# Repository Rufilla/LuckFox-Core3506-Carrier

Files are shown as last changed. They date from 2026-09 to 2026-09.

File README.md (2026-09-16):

<!-- {{LOGO — add the Rufilla logo here once an asset lives in this repo, e.g. ![Rufilla](docs/images/rufilla-logo.png)}} -->

# Foxbridge — Luckfox Core3506 carrier board


<!-- Add build and release badges when CI is set up. -->

A carrier board for the [Luckfox Core3506](https://wiki.luckfox.com/Core3506/Introduction/)
system-on-module (SoM), for anyone who wants the RK3506 on a Raspberry Pi Model B-sized board
(85 × 56 mm) with Ethernet, USB-C, a DSI display & a 40-pin header. Designed in KiCad 10 by
Rufilla Ltd., from the [Luckfox Lyra Pi](https://www.luckfox.com/Luckfox-Lyra-Pi) reference
design. Revision A is a prototype: it has been built & brought up, with three hardware faults.

| | |
|---|---|
| **Client** | Internal |
| **Project code** | Foxbridge |
| **Status** | Prototype — Revision A built & reworked; Revision B in design |

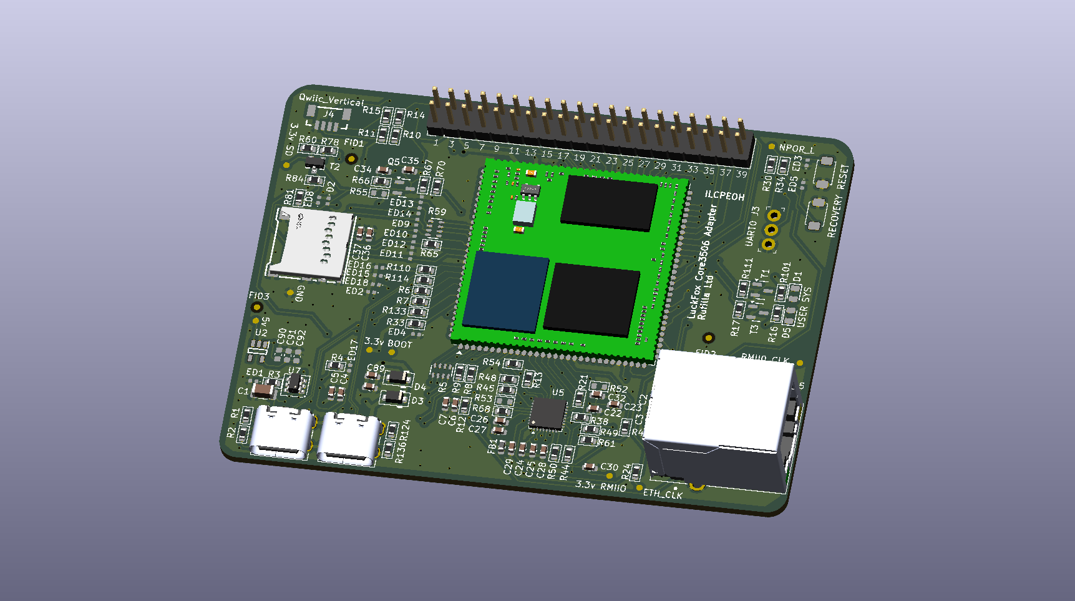
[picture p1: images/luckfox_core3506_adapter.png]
Foxbridge carrier board


> **Revision A has been built & brought up with three hardware faults.** USB host (OTG1) does
> not work without two reworks. Read the [errata](docs/errata.md) before ordering boards.

## Overview

The board breaks the Core3506 SoM out to a Raspberry Pi Model B footprint. Each subsystem has
its own schematic sheet; [docs/design-notes.md](docs/design-notes.md) explains how each one
works & why.

- **USB-C ×2** — OTG0 (device, flashing & 5 V power input) & OTG1 (host, 500 mA current limit)
- **10/100 Ethernet** — CH182H2 PHY on RMII0, HR911105A RJ45 with integrated magnetics
- **MIPI DSI** — 2-lane, 22-pin 0.5 mm FPC for the Luckfox 7" DSI touchscreen (SKU 25265)
- **40-pin header** — Raspberry Pi-compatible pinout
- **microSD** — TF-110 socket with power switching; see errata E4 for the eMMC SoM
- **RESET & RECOVERY buttons**; UART0 header & Qwiic connector (both not fitted)
- **4-layer, 1.6 mm, impedance-controlled** — built for JLCPCB Economic PCBA

Out of scope for this design:

- No on-board 3.3 V regulator is fitted; the SoM supplies `VCC_3V3`. U2 is reserved for a
  future Wi-Fi/Bluetooth module.
- No Wi-Fi or Bluetooth.
- Power comes only from 5 V on the OTG0 USB-C port — no barrel jack & no PoE.
- The microSD slot does not work with the Core3506 variant that has on-module eMMC.
- No MASKROM button & no mounting holes in Revision A.

## Requirements

**Hardware**

- Luckfox Core3506 SoM (RK3506), fitted to a Foxbridge carrier board, revision A
- USB-C cable on OTG0 for power & flashing; 3.3 V USB-UART on the UART0 header for a console
- Optional: Luckfox 7" DSI touchscreen (SKU 25265), microSD card, Ethernet cable

**Software**

- KiCad 10.0 or later. Checked with 10.0.6.
- [Fabrication Toolkit](https://github.com/bennymeg/JLC-Plugin-for-KiCad) plugin, to regenerate
  the JLCPCB production files
- Third-party symbol & footprint libraries, needed only to update a part from its library:

| Nickname in the design | Library | Install from |
|---|---|---|
| `PCM_SparkFun-*` | SparkFun KiCad Libraries | Plugin & Content Manager (PCM) |
| `PCM_*_AKL` | [Alternate KiCad Library](https://github.com/DawidCislo/Alternate-KiCad-Library) | PCM |
| `PCM_JLCPCB*` | [JLCPCB KiCad Library](https://github.com/CDFER/JLCPCB-Kicad-Library) | PCM, after adding CD_FER's repository |
| `digikey-footprints`, `dk_*` | [Digi-Key KiCad Library](https://github.com/Digi-Key/digikey-kicad-library) | Clone & register by hand (J3 only) |

PCM libraries resolve only with the default nickname prefix `PCM_` (**Preferences → Packages
& Updates**).

## Getting the source

```bash
git clone https://github.com/Rufilla/LuckFox-Core3506-Carrier.git
cd LuckFox-Core3506-Carrier
```

## Building

Open `luckfox_core3506_adapter.kicad_pro` in KiCad. The schematic & board carry a copy of every
symbol & footprint, so the design opens, plots & runs ERC/DRC without the third-party libraries
above. Parts specific to this board are in the project library `lib/` (nickname `Foxbridge`),
with their 3D models embedded.

Regenerate the fabrication outputs from the PCB editor with **Tools → External Plugins →
Fabrication Toolkit**. It reads `fabrication-toolkit-options.json`, excludes do-not-populate
parts & writes the Gerbers, drill, BOM & placement files that are committed in `production/`.

## Flashing / deployment

Ordering Revision A from JLCPCB, in full, is in
[docs/manufacturing.md](docs/manufacturing.md#order-from-jlcpcb). In short:

| File | Upload as |
|---|---|
| `production/luckfox_core3506_adapter.zip` | Gerbers & drill |
| `production/bom.csv` | Bill of materials |
| `production/positions.csv` | Component placement (CPL) |

Order Economic PCBA. Three parts are soldered by hand — J1 (RJ45), H1 (2 × 20 pin header) &
U1 (Core3506) — and the placement preview needs the rotation & offset corrections listed in the
manufacturing notes.

> **NOTE:** the files in `production/` reproduce Revision A exactly, including the faults in
> [docs/errata.md](docs/errata.md). Boards built from them need the E1 & E2 reworks before USB
> host works.

## Usage

Power the board from 5 V over the OTG0 USB-C port; the same port flashes the SoM. The console
is on the UART0 header. Ethernet, DSI & the 40-pin header need no board-level configuration.

Before trusting a freshly built board, check it against the reworks in
[docs/errata.md](docs/errata.md): R3 moved (E1) & R6/R7 bridged (E2). Photographs of both are
in `images/`.

## Testing

Run electrical rules & design rules from the project directory:

```bash
kicad-cli sch erc luckfox_core3506_adapter.kicad_sch
kicad-cli pcb drc --schematic-parity luckfox_core3506_adapter.kicad_pcb
```

Every outstanding ERC & DRC report is listed, with its cause & whether it is a real fault, in
[docs/manufacturing.md](docs/manufacturing.md#erc--drc-status). Schematic parity & unconnected
items are both zero.

## Project structure

```
luckfox_core3506_adapter.kicad_pro   KiCad project; the root schematic, 10 sheets & board sit beside it
lib/                                 Project symbol library & footprint library
production/                          Revision A files as ordered from JLCPCB: Gerbers & drill (.zip), BOM, placement, IPC netlist
docs/                                Design notes, errata, manufacturing notes & the Revision B checklist
images/                              Board render & rework photographs
```

Documentation:

- [Design notes](docs/design-notes.md) — how each subsystem works & why
- [Errata](docs/errata.md) — Revision A faults, reworks & limitations
- [Manufacturing](docs/manufacturing.md) — stack-up, ordering from JLCPCB, ERC/DRC status
- [Revision B checklist](docs/rev-b-checklist.md) — changes planned for the respin

## Security

Report a security problem to [hello@rufilla.com](mailto:hello@rufilla.com) rather than through
a public issue. This repository holds hardware design files only, so no software bill of
materials (SBOM) is produced; the bill of materials for the board is `production/bom.csv`.

## Contributing

Report problems & suggestions through GitHub issues, & send changes as pull requests.

## Licence

Copyright 2026 Rufilla Ltd. Licensed under the [Apache License 2.0](LICENSE).

Symbols, footprints & 3D models copied from third-party libraries remain under their own
licences.

## Support

Rufilla Ltd · Building D5, Culham Campus, Abingdon, Oxfordshire, UK, OX14 3DB
[hello@rufilla.com](mailto:hello@rufilla.com) · +44 (0)1865 601201 · [www.rufilla.com](https://www.rufilla.com)

© 2026 Rufilla Ltd

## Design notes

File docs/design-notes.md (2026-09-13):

# Design notes

How each subsystem of Revision A works & why it was designed that way. Faults found at
bring-up are in [errata.md](errata.md); fabrication detail is in
[manufacturing.md](manufacturing.md).

Contents: [Schematic](#schematic) · [Power](#power) · [USB](#usb) · [Ethernet](#ethernet) ·
[microSD](#microsd) · [DSI display](#dsi-display) · [Boot & reset](#boot--reset) ·
[Debug](#debug) · [LEDs](#leds) · [SoM pin mapping](#som-pin-mapping)

---

## Schematic

Hierarchical, 10 sheets. The SoM, U1 (`Core3506_multipart`), is an 8-unit symbol whose units
are placed on the sheets that use them.

| Page | Sheet |
|---|---|
| 1 | Contents & revisions |
| 2 | Block diagram |
| 3 | Power tree |
| 4 | Power regulation |
| 5 | USB interfaces |
| 6 | Ethernet |
| 7 | TF card |
| 8 | DSI |
| 9 | GPIO header & boot keys |
| 10 | Misc — test points, LEDs, fiducials |

## Power

- **Input:** 5 V from the OTG0 USB-C port (H5) through D3 (MBR230SFT Schottky) to
  `VCC5V0_SYS`. D3 stops OTG1 VBUS back-feeding OTG0.
- **`VCC5V0_SYS` TVS:** ED17 (ESD5451N, 5 V stand-off, 13 V clamp).
- **3.3 V:** supplied by the PMIC on the SoM. U2 (ME6217C33M5G LDO) is not fitted; it is
  reserved for a future Wi-Fi/Bluetooth module.
- **OTG1 VBUS:** U7 (TPS2553DBVR) power switch, current limit set to 500 mA by R4 (56 kΩ).
  ED1 (ESD5451N) protects its output. Does not switch on in Revision A — see errata E1.
- **Ethernet analogue supply:** FB1 (330 Ω at 100 MHz) isolates `VCCA3V3_RMII0` from `VCC_3V3`.

## USB

### OTG0 — device, flashing & power input (H5)

- CC pull-downs (Rd, i.e. USB-C sink): R136 & R124, 5.1 kΩ.
- D+/D− series resistors R110 & R114, 22 Ω — the same value that breaks OTG1 (errata E2).
- ESD: ED18 & ED2 (ESD5341N).
- VBUSDET (U1 pin 113) tied to `VCC_3V3` through R133 (10 kΩ); ID (pin 112) left
  unconnected. Both follow the Lyra Pi.

### OTG1 — host, 500 mA (H6)

- CC pull-ups (Rp, i.e. USB-C source): R1 & R2, 56 kΩ to OTG1 VBUS, advertising Default USB
  power.
- D+/D− series resistors R6 & R7, 22 Ω. **Wrong for high speed** — see errata E2.
- ESD: ED15 & ED16 (ESD5341N).

## Ethernet

### CH182H2 PHY (U5)

> **NOTE:** the CH182H2 is not strap-compatible with the CH182H1. The RMII-mode strap moved
> from pin 27 (COL) on the H1 to pin 8 (RXDV) on the H2. Use the H2 tables in datasheet
> CH182DS1; CH182H1 designs give the wrong strap assignments.

| Function | Setting | Parts |
|---|---|---|
| PHY address | 0x01 (PA0 = 1 via LED0 pull-up, PA1 = 0 via LED1 pull-down) | — |
| Mode | RMII: RXDV (pin 8) pulled high | R50, 4.7 kΩ |
| Clock | MAC drives 50 MHz REFCLK; CLKCTL pulled high | R38, 4.7 kΩ |
| 25 MHz XI | From SoM `ETH_CLK0_25M_OUT`; no crystal | R24, 0 Ω |
| LOS | Low — LED function, not wake-on-LAN | R61, 4.7 kΩ to GND |
| RSTB | Internal pull-up is enough | R52, 4.7 kΩ, not fitted |
| Idle state | CRS_DV & RXER pulled low | R45 & R68, 4.7 kΩ |

### RJ45 (J1, HR911105A)

- Integrated magnetics give galvanic isolation, so the MDI pairs carry no ESD diodes.
- Centre-tap decoupling: C2 & C3, 100 nF.
- Link & activity LEDs driven from the CH182H2 LED0 & LED1 pins.

### Routing

- MDI: 100 Ω differential; intra-pair match within 1.3 mm; ≥ 0.75 mm between pairs.
- RMII: 50 Ω single-ended; data matched to REF_CLK within 10 mm.

## microSD

- Socket: J2 (TF-110, LCSC C266613).
- Power: Q5 (SI2301CDS P-channel MOSFET) switches `VCC_3V3` to `VCC3V3_SD`, gate driven from
  `SDMMC_PWREN` through R70.
- Card detect: T2 (MMBT3906 PNP).
- ESD: ED8–ED14 (ESD5341N) on CLK, CMD, D0–D3 & card detect; D2 on `VCC3V3_SD`.
- Series resistors: R59 (4 × 22 Ω array) on D0–D3, R65 (22 Ω) on CMD. CLK has none.
- Routing: matched to CLK within about 7.5 mm, inside the tolerance for 50 MHz. CMD, D2 & D3
  change to B.Cu through two vias each.

The slot is electrically dead when the SoM has on-module eMMC — a limitation of the RK3506,
explained in errata E4.

## DSI display

Target display: Luckfox 7" DSI touchscreen (SKU 25265) — 800 × 480 IPS, 5-point capacitive
touch — through H4 (22-pin 0.5 mm FPC, LCSC C262668). Sold by
[Luckfox](https://www.luckfox.com/EN-7inch-DSI-Touchscreen) & Waveshare.

| FPC pin | Signal | Connection |
|---|---|---|
| 1 | `VCC_3V3` | Display power |
| 2 | `I2C2_SDA` | Touch; R15 22 Ω series, R11 3.3 kΩ pull-up |
| 3 | `I2C2_SCL` | Touch; R14 22 Ω series, R10 3.3 kΩ pull-up |
| 4, 7, 10, 13, 16, 19, 22 | GND | |
| 5 | `LCD_IO1` | GPIO1_C4 (U1 pin 34) — LCD reset, R12 10 kΩ pull-up |
| 6 | `LCD_IO0` | GPIO0_B7 (U1 pin 63) — backlight enable |
| 8, 9, 11, 12 | — | Not connected |
| 14–15 | `DSI_TX_CLKN/P` | U1 pins 1 & 2; 2.2 Ω series (R5 array) |
| 17–18 | `DSI_TX_D1N/P` | U1 pins 4 & 5; 2.2 Ω series (R5 array) |
| 20–21 | `DSI_TX_D0N/P` | U1 pins 7 & 8; 2.2 Ω series (R8, R9) |

Departures from the Lyra Pi:

- **No LCD power switch** (WPM3407-3/TR). The board is always powered from USB, & the DSI
  driver sequences reset independently of power.
- **No backlight driver** (TCS7191A). The display has its own; only an enable is needed.
- **2.2 Ω instead of 0 Ω** on all six DSI lines, for consistent damping.
- **No ESD on the FPC.** The connector is internal, & the DSI lanes are sensitive to added
  capacitance.

`I2C2_SDA` (U1 pin 43, GPIO1_B3) & `I2C2_SCL` (U1 pin 36, GPIO1_C2) are shared by the touch
panel, the 40-pin header (H1 pins 3 & 5) & the Qwiic connector, with no jumpers.

## Boot & reset

- **RESET** (Key1): pulls `NPOR_L` (U1 pin 80) low through R30 (100 Ω), ESD by ED3. The SoM
  PMIC drives `NPOR_L` push-pull, so there is no external pull-up — as on the Lyra Pi.
- **RECOVERY** (Key2): pulls `SARADC_IN1` low through R34 (100 Ω), ESD by ED5. A key read by
  software after boot; it does **not** enter maskrom (errata E5).
- **Maskrom strap:** `SARADC_IN0_BOOT` (U1 pin 114) reaches test point TP6 through R33
  (100 Ω), ESD by ED4. No button is fitted.

## Debug

Neither connector is fitted in Revision A.

- **J3** — UART0, 3-pin 2.54 mm header: U1 pins 56 & 57 (GPIO0_C7, GPIO0_C6) & GND. UART0 is
  also on the 40-pin header.
- **J4** — Qwiic/STEMMA QT (JST-SH 4-pin): `I2C2_SDA`, `I2C2_SCL`, `VCC_3V3`, GND.

## LEDs

Both green 0805, each switched low-side by an SS8050 NPN from a SoM GPIO.

| LED | Transistor | GPIO | Base resistor | LED resistor |
|---|---|---|---|---|
| D1 (SYS) | T1 | GPIO1_A0 (U1 pin 55) | R111, 1 kΩ | R101, 470 Ω |
| D5 (USER) | T3 | GPIO1_A6 (U1 pin 49) | R17, 1 kΩ | R16, 470 Ω |

## SoM pin mapping

| U1 unit | Sheet | Signals |
|---|---|---|
| 1 | Power regulation | `VCC5V0_SYS`, `VCC_3V3`, `VCC_1V8` |
| 2 | USB interfaces | OTG0 D+/D− (108–109), OTG1 D+/D− (110–111), ID (112), VBUSDET (113) |
| 3 | Ethernet | RMII0, `ETH_CLK0_25M_OUT`, MDC/MDIO |
| 4 | TF card | SDMMC (101–106) |
| 5 & 6 | GPIO header & boot keys | `NPOR_L` (80), SARADC, GPIO0_B1–B6, GPIO0_C6–C7, GPIO1_A3–A5, GPIO1_D2–D3 |
| 7 | DSI | DSI CLK, D0 & D1 (1–8), `LCD_IO0` (63), `LCD_IO1` (34) |
| 8 | Misc | LED drive & power |

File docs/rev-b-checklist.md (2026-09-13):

# Revision B checklist

Changes planned for the respin. Causes & reworks for the faults are in [errata.md](errata.md).

## Faults — must fix

- [ ] **E1 — OTG1 VBUS switch.** Connect R3 pin 1 to U7 pin 1 (IN), not pin 6 (OUT).
- [ ] **E2 — USB series resistors.** R6 & R7 → 0 Ω or removed; the same for R110 & R114 on OTG0.
- [ ] **E3 — USB-C spacing.** Move H5 & H6 apart so two cables fit at once.

## Improvements

- [ ] **MASKROM button** from `SARADC_IN0_BOOT` to GND through R33 & ED4, labelled MASKROM.
      It is the only input that makes the RK3506 BootROM enter maskrom (errata E5).
- [ ] **Key2** — relabel from RECOVERY to USER or KEY, or remove it if no firmware reads
      `SARADC_IN1`.
- [ ] **U7 EN to a free GPIO**, instead of a fixed pull-up. Linux can then power-cycle OTG1, &
      `vcc5v0_otg1` gets a `gpio` property instead of `regulator-fixed` with `always-on`.
- [ ] **U7 FAULT# to a free interrupt-capable GPIO** (open-drain). Linux can then log OTG1
      over-current & thermal shutdown instead of browning out silently.
- [ ] **Silkscreen warning beside J2:** "SD slot non-functional with on-module eMMC SoM
      (Core3506-0808)" (errata E4).
- [ ] **Silkscreen:** align the 40-pin header numbering on the bottom side, & raise its text
      thickness to 0.15 mm.
- [ ] **Mounting holes:** add four, one in each corner.
- [ ] **Header pins** for `SARADC_IN0_BOOT` & `NPOR_L`, which are test points only today.

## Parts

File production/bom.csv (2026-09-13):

Designator | Footprint | Quantity | Value | LCSC Part #
C1 | 1206 | 1 | 100uF | C15008
C2, C23, C24, C26, C28, C29, C3, C32, C34, C35, C37, C4, C5, C6, C88 | 0603 | 15 | 100nF | C14663
C22, C30, C36 | 0603 | 3 | 4.7uF | C19666
C25, C27 | 0603 | 2 | 1uF | C15849
C7, C89 | 0603 | 2 | 10uF | C19702
D1 | D_0805 | 1 | SYS | C2297
D2, ED10, ED11, ED12, ED13, ED14, ED15, ED16, ED18, ED2, ED3, ED4, ED5, ED8, ED9 | 0402 | 15 | ESD5341N | C20612964
D3 | D_SOD-123F | 1 | MBR230SFT | C5377812
D4 | D_SOD-123F | 1 | SMF5.0A | C19077498
D5 | D_0805 | 1 | USER | C2297
ED1, ED17 | 0402 | 2 | ESD5451N | C2936977
FB1 | 0603 | 1 | 330Ω@100MHz | C88989
H4 | FPC_1x22_P0.5mm_Horizontal_BottomContact | 1 | Conn_01x22_FPC_0.5mm | C262668
H5, H6 | TYPE-C_16PIN_2MD_073 | 2 | TYPE-C_16PIN_2MD__073_ | C2765186
J1 | HANRUN_HR911105A | 1 | HR911105A | C12074
J2 | TF-SMD_TF-110 | 1 | TF-110 | C266613
KEY1 | SW_TS-1088-AR02016 | 1 | RESET | C720477
KEY2 | SW_TS-1088-AR02016 | 1 | RECOVERY | C720477
Q5 | Q_SOT-23 | 1 | SI2301CDS-T1-GE3 | C10487
R1, R2, R4 | 0603 | 3 | 56k | C23206
R10, R11 | 0603 | 2 | 3.3k | C22978
R101, R16 | 0603 | 2 | 470R | C23179
R110, R114, R14, R15, R42, R44, R48, R6, R65, R7 | 0603 | 10 | 22R | C23345
R111, R17, R78, R81 | 0603 | 4 | 1k | C21190
R12, R133, R60, R67, R70, R84 | 0603 | 6 | 10k | C25804
R124, R136 | 0603 | 2 | 5.1k | C23186
R13, R21, R24 | 0603 | 3 | 0R | C21189
R25, R26 | 0603 | 2 | 510R | C23193
R3, R66 | 0603 | 2 | 100k | C25803
R30, R33, R34 | 0603 | 3 | 100R | C22775
R38, R45, R49, R50, R61, R68 | 0603 | 6 | 4.7K | C23162
R5 | R_0603x4 | 1 | 2.2Ω | C12002
R54 | 0603 | 1 | 1.8k | C4177
R59 | R_0603x4 | 1 | 22R | C12008
R8, R9 | 0603 | 2 | 2.2Ω | C22939
T1, T3 | Q_SOT-23 | 2 | SS8050 200-350 | C2150
T2 | SOT23-3 | 1 | MMBT3906 | C2149
U5 | QFN-32-1EP_5x5mm_P0.5mm_EP3.45x3.45mm | 1 | CH182H2 | C41427683
U7 | SOT-23-6 | 1 | TPS2553DBVR | C55266

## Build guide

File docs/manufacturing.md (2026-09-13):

# Manufacturing

Stack-up, impedance control, ordering Revision A from JLCPCB & the current ERC/DRC results.

---

## Stack-up

JLCPCB **JLC04161H-3313**: 4 layers, 1.6 mm, ENIG. Values below are JLCPCB's; the KiCad board
stack-up rounds them.

| Layer | Thickness | Use |
|---|---|---|
| F.Cu | 35 µm (1 oz) | Signals & components |
| Prepreg 3313 | 0.0994 mm, εr 4.05 | |
| In1.Cu | 15.2 µm (0.5 oz) | GND plane |
| Core | 1.265 mm, εr 4.6 | |
| In2.Cu | 15.2 µm (0.5 oz) | 3.3 V & 5 V planes |
| Prepreg 3313 | 0.0994 mm, εr 4.05 | |
| B.Cu | 35 µm (1 oz) | Signals |

## Impedance control

Net classes are calculated for microstrip on F.Cu over the In1.Cu GND plane.

| Net class | Track width | Pair gap | Target |
|---|---|---|---|
| DSI | 0.09 mm | 0.13 mm | 100 Ω differential |
| Ethernet (MDI) | 0.09 mm | 0.13 mm | 100 Ω differential |
| USB | 0.117 mm | 0.13 mm | 90 Ω differential |
| RMII | 0.13 mm | — | 50 Ω single-ended |
| Power | 0.6 mm | — | — |
| Default | 0.2 mm | — | — |

Stitching vias surround the high-speed signals on F.Cu only. B.Cu carries just short layer
transitions of those signals, & its reference plane is In2.Cu.

JLCPCB's fabrication limits are encoded as custom DRC rules in
`luckfox_core3506_adapter.kicad_dru`. Track width & spacing minima are in **Board Setup →
Design Rules → Constraints** instead.

## Order from JLCPCB

> **NOTE:** the files in `production/` reproduce Revision A exactly, including the faults in
> [errata.md](errata.md). Boards built from them need the E1 & E2 reworks before USB host
> works.

The files were generated by the Fabrication Toolkit plugin
([JLC-Plugin-for-KiCad](https://github.com/bennymeg/JLC-Plugin-for-KiCad)) using
`fabrication-toolkit-options.json`, which excludes parts marked do-not-populate (DNP).

| File | Upload as |
|---|---|
| `production/luckfox_core3506_adapter.zip` | Gerbers & drill |
| `production/bom.csv` | Bill of materials |
| `production/positions.csv` | Component placement (CPL) |

Order Economic PCBA. JLCPCB does not assemble three parts, which are soldered by hand: J1
(HR911105A RJ45), H1 (2 × 20 pin header) & U1 (Core3506). JLCPCB rejected U1 for assembly.

### Correct the placement file

The toolkit exports with `AUTO TRANSLATE` (origin correction) on. Make these changes in
JLCPCB's placement preview after uploading `positions.csv`:

1. Remove U1 from the placement list.
2. Move H5 & H6 (USB-C, LCSC C2765186) by **+1.6 mm in Y**.
3. Rotate:

| Ref | Part | Rotation |
|---|---|---|
| J1 | HR911105A (RJ45) | +180° |
| T1 | SS8050 | +180° |
| T2 | MMBT3906 | +180° |
| T3 | SS8050 | +180° |
| Q5 | SI2301CDS | +180° |
| U5 | CH182H2 (Ethernet PHY) | −90° |
| R5 | 2.2 Ω array (4 × 0603) | +90° |
| R59 | 22 Ω array (4 × 0603) | +90° |

## ERC & DRC status

Observed with KiCad 10.0.6, its bundled libraries & the SparkFun library. Run from the project
directory:

```bash
kicad-cli sch erc luckfox_core3506_adapter.kicad_sch
kicad-cli pcb drc --schematic-parity luckfox_core3506_adapter.kicad_pcb
```

Where:
- `--schematic-parity` also compares the board against the schematic

Without the third-party libraries installed, both reports add one warning per part that uses
them (`lib_symbol_issues`, `footprint_link_issues`, `lib_footprint_issues`). Those warnings
concern the library tables only, not the design.

### ERC

| Report | Cause | Real fault |
|---|---|---|
| Power output connected to power output, `VCC_3V3` | The SoM PMIC drives `VCC_3V3` & a `PWR_FLAG` is also placed on it | No |
| J2 pin 4 (VDD) not driven | Supplied through Q5, which ERC does not treat as a source | No |
| `#PWR01` (GND) not driven | No `PWR_FLAG` on GND | No |
| 4 × `C_Small`, 1 × `Qwiic_Vertical` differ from library | The design copies differ from the current library versions | No |

### DRC

| Count | Report | Cause |
|---|---|---|
| 26 | Copper to board edge, U1 | Castellated SoM pads beside the cut-out; manufacturable |
| 16 | Silkscreen clipped by board edge, U1 | SoM outline overlaps the cut-out; the fab clips it |
| 8 | Hole clearance, H5 & H6 | USB-C GND pads 0.165 mm from the connector's locating holes; rule is 0.25 mm |
| 1 | Silkscreen text thickness | 40-pin header numbering is 0.1 mm, below the 0.15 mm rule |
| 6 | Footprint differs from library, ED9–ED14 | Board copies of `Diode_SMD:D_0402_1005Metric` differ from the current library |
| 0 | Schematic parity | |
| 0 | Unconnected items | |

The ESD diodes (D2, ED1–ED5, ED8–ED18) are DFN1006 parts on `D_0402_1005Metric` footprints.
The two land patterns are close — 0.59 × 0.64 mm pads at 0.97 mm pitch against 0.50 × 0.60 mm
at 0.80 mm for `D_DFN1006-2L` — & the 0402 pads cover the DFN1006 terminals. Revision A was
assembled on them.

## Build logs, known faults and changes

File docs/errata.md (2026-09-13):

# Revision A errata

Faults & limitations found while bringing up Revision A, with the rework applied to the
built boards. The Revision B changes are tracked in [rev-b-checklist.md](rev-b-checklist.md).

| ID | Problem | Severity | Rework on Revision A |
|---|---|---|---|
| [E1](#e1-otg1-vbus-switch-never-turns-on) | OTG1 VBUS switch never turns on | Critical | Yes — R3 moved |
| [E2](#e2-series-resistors-break-usb-high-speed) | 22 Ω series resistors break USB high speed | Critical | Yes — R6 & R7 bridged |
| [E3](#e3-usb-c-connectors-too-close) | USB-C connectors too close for two cables | Minor | None possible |
| [E4](#e4-microsd-slot-dead-with-the-emmc-som) | microSD slot dead with the eMMC SoM | Limitation | None possible |
| [E5](#e5-recovery-button-does-not-enter-maskrom) | RECOVERY button does not enter maskrom | Minor | Use TP6 |

---

## E1: OTG1 VBUS switch never turns on

**Symptom:** no VBUS on the OTG1 USB-C port (H6); USB devices are not powered.

**Cause:** U7 (TPS2553, active-high EN) has no pull-up to its input. As built:

```
U7 OUT (pin 6) ── R3 100 kΩ ──┬── EN (pin 3)
                              ├── FAULT# (pin 4)
                              └── C4 100 nF ── GND
```

R3 pulls EN up to OUT, which stays at 0 V until the switch is on, so EN never rises. FAULT#
is also tied directly to EN.

**Rework (applied 2026-04-12):** lift R3 pin 1 off OUT & wire it to U7 pin 1 (IN), making R3
an EN pull-up to `VCC5V0_SYS`. 5 V was confirmed at H6.

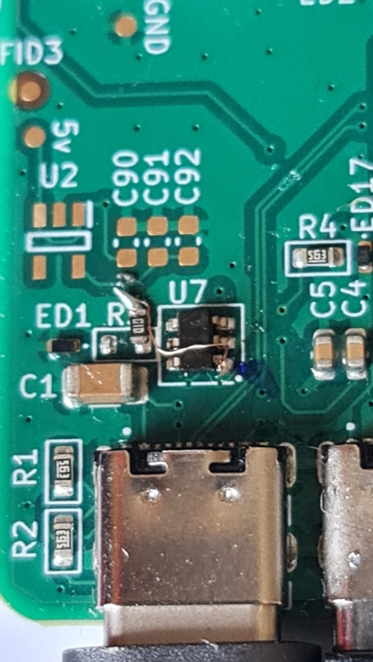
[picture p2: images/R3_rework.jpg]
E1 rework — R3 wired to U7 pin 1


**Revision B:** connect R3 pin 1 to IN, not OUT. Check the FAULT#/EN auto-retry network against
the TPS2553 datasheet (SLVS841) before layout, or drive EN & read FAULT# from GPIOs as
proposed in the checklist.

## E2: series resistors break USB high speed

**Symptom:** the OTG1 host port enumerates no device. Reproduced with a USB 3 flash drive &
a USB 2 stick, so neither the device nor the cable is at fault. Kernel log:

```
usb usb1-port1: Cannot enable. Maybe the USB cable is bad?
usb usb1-port1: attempt power cycle
```

**Cause (found 2026-04-13):** R6 & R7, 22 Ω in series with D+/D− between H6 & the SoM. In
high-speed mode the PHY provides its own 45 Ω termination; the added resistance attenuates
the chirp handshake during port reset, & it fails. 22 Ω suits full-speed signalling only.
The Lyra Pi uses 2.2 Ω, effectively a 0 Ω placeholder.

**Rework:** replace R6 & R7 with 0 Ω, or bridge each pair of pads with solder. No software
change is needed.

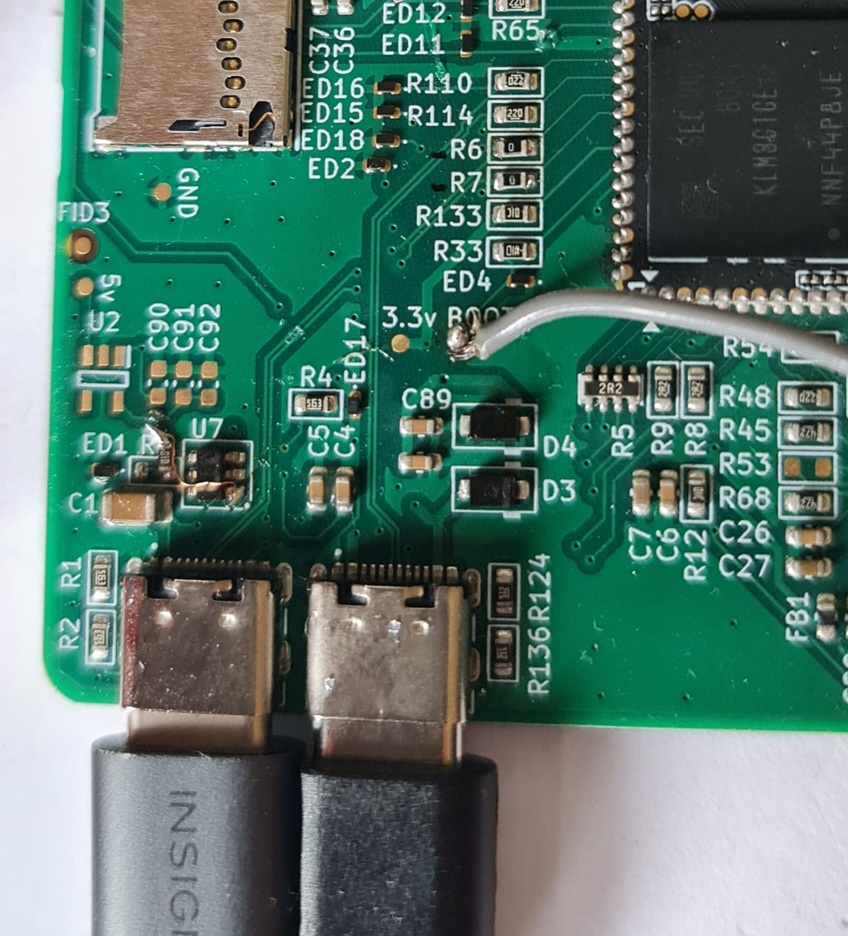
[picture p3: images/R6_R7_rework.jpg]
E2 rework — R6 & R7 bridged


**Revision B:** R6 & R7 → 0 Ω, or remove them. OTG0 has the same 22 Ω values (R110, R114)
& should get the same change; it has not been reworked.

## E3: USB-C connectors too close

**Symptom:** H5 (OTG0) & H6 (OTG1) are so close that two USB-C cables cannot be plugged in
at once — the plug overmoulds collide.

**Revision B:** increase the centre-to-centre spacing. Allow for overmoulds up to about 12 mm
wide.

## E4: microSD slot dead with the eMMC SoM

**Symptom:** the Core3506-0808 SoM does not see a card in J2.

**Cause:** the RK3506 has one SDMMC controller (`mmc@ff480000`). The Core3506-0808 connects
its 8 GB eMMC to that controller permanently, so the carrier's slot has no controller to use.
This is a limitation of the SoC — J2 is wired correctly & no rework can fix it. The RV1106, by
comparison, has two MMC controllers.

Confirmed by the Forlinx OK3506 manual, by Luckfox selling separate SD-boot & flash-boot Lyra
SKUs, & on Revision A: with the eMMC idbloader zeroed, the BootROM entered maskrom instead of
booting from SD.

**Workarounds:** a Core3506 variant without eMMC
([Luckfox](https://www.luckfox.com/Core3506?ci=672)) makes the slot work on the same board.
With the eMMC SoM, use USB mass storage on OTG1 (after the E1 & E2 reworks) or SPI flash on
the 40-pin header.

**Revision B:** keep the slot, which the eMMC-less SoM needs, & add a silkscreen warning
beside J2.

## E5: RECOVERY button does not enter maskrom

**Symptom:** holding RECOVERY (Key2) during reset does not put the RK3506 into maskrom.

**Cause:** the board copies the Lyra Pi's net names, & the Lyra Pi has two boot inputs on
different ADC pins. Foxbridge fitted the button to the wrong one. The difference only showed at
bring-up, because the Core3506 cannot be booted before it is soldered to a carrier.

| Lyra Pi key | SoC pin | Purpose | On Foxbridge |
|---|---|---|---|
| `MASKROM_Key` | `SARADC_IN0_BOOT` | Held low at power-on reset → BootROM enters maskrom | No button — R33, ED4 & test point TP6 only |
| `RECOVERY_Key` | `SARADC_IN1` | Key read by U-Boot or Linux; no effect on the BootROM | Key2, labelled RECOVERY |

**Enter maskrom on Revision A** by one of:

1. Shorting TP6 to GND during power-on reset. This is what the missing MASKROM button would
   do.
2. Shorting the MASKROM test points on the Core3506 itself during power-up.
3. Invalidating the eMMC idbloader, so the BootROM falls through to USB maskrom.

   > **NOTE:** this erases the bootloader. The board will not boot again until it is
   > reflashed over USB in maskrom mode.

   Run `rkdeveloptool ef`, or zero the first sectors of the eMMC.

**Revision B:** fit a MASKROM button from `SARADC_IN0_BOOT` to GND through R33 & ED4. Relabel
Key2 (USER or KEY), or remove it if no firmware reads `SARADC_IN1`.

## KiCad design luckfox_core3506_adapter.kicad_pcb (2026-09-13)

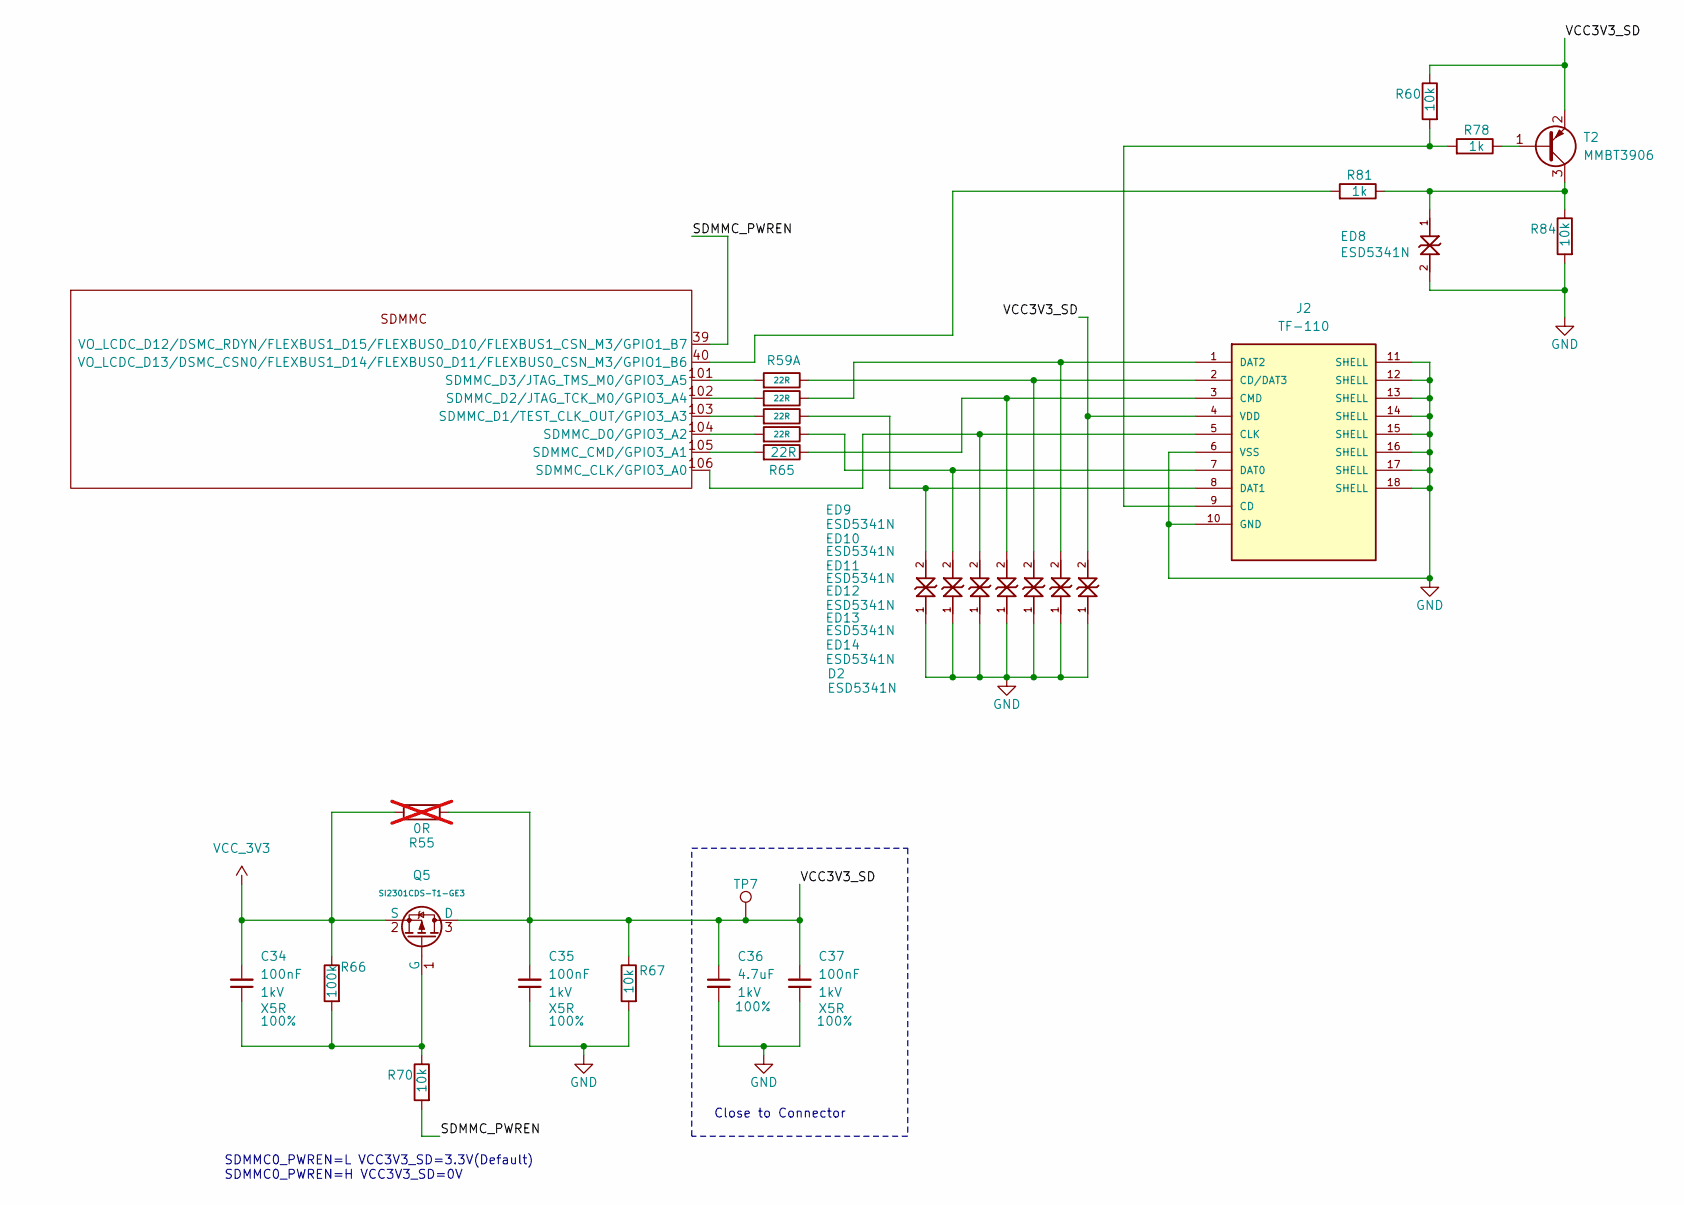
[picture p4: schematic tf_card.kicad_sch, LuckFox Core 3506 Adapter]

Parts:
C34, C35, C37: 100nF; C_0603_1608Metric; Voltage 1kV; Tolerance 100%; LCSC C14663
C36: 4.7uF; C_0603_1608Metric; Voltage 1kV; Tolerance 100%; LCSC C19666
D2: ESD5341N; D_0402_1005Metric; LCSC C20612964
ED8, ED9, ED10, ED11, ED12, ED13, ED14: ESD5341N; D_0402_1005Metric; LCSC C20612964
J2: TF-110; TF-SMD_TF-110; LCSC C266613
Q5: SI2301CDS-T1-GE3; Q_SOT-23; Part SI2301CDS-T1-GE3; LCSC C10487
R55: 0R; R_0603_1608Metric; LCSC C21189; not fitted
R59: 22R; R_0603x4; Tolerance ±5%; Part 4D03WGJ0220T5E; LCSC C12008
R60, R67, R70, R84: 10k; R_0603_1608Metric; LCSC C25804
R65: 22R; R_0603_1608Metric; LCSC C23345
R66: 100k; R_0603_1608Metric; LCSC C25803
R78, R81: 1k; R_0603_1608Metric; LCSC C21190
T2: MMBT3906; SOT23-3; LCSC C2149
TP7: 3.3v SD; TestPoint-1.0mm
U1: CORE3506_[32_32]_120P

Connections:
/TF card/SDMMC_PWREN: R70.1, U1.39 (VO_LCDC_D12/DSMC_RDYN/FLEXBUS1_D15/FLEX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)
/TF card/VCC3V3_SD: C35.2, C36.1, C37.2, D2.2 (A2), J2.4 (VDD), Q5.3 (D), R55.1, R60.2, R67.2, T2.2 (E), TP7.1 (1_1)
GND: C35.1, C36.2, C37.1, D2.1 (A1), ED8.2 (A2), ED9.1 (A1), ED10.1 (A1), ED11.1 (A1), ED12.1 (A1), ED13.1 (A1), ED14.1 (A1), J2.6 (VSS), J2.10 (GND), J2.11 (SHELL), J2.12 (SHELL), J2.13 (SHELL), J2.14 (SHELL), J2.15 (SHELL), J2.16 (SHELL), J2.17 (SHELL), J2.18 (SHELL), R67.1, R84.1; also elsewhere on the board
unnamed: ED8.1 (A1), R81.2, R84.2, T2.3 (C)
unnamed: ED9.2 (A2), J2.8 (DAT1), R59.7
unnamed: ED10.2 (A2), J2.7 (DAT0), R59.8
unnamed: ED11.2 (A2), J2.5 (CLK), U1.106 (SDMMC_CLK/GPIO3_A0)
unnamed: ED12.2 (A2), J2.3 (CMD), R65.2
unnamed: ED13.2 (A2), J2.2 (CD/DAT3), R59.5
unnamed: ED14.2 (A2), J2.1 (DAT2), R59.6
unnamed: J2.9 (CD), R60.1, R78.1
unnamed: C34.1, Q5.1 (G), R66.1, R70.2
unnamed: R78.2, T2.1 (B)
unnamed: R65.1, U1.105 (SDMMC_CMD/GPIO3_A1)
unnamed: R59.1, U1.104 (SDMMC_D0/GPIO3_A2)
unnamed: R59.2, U1.103 (SDMMC_D1/TEST_CLK_OUT/GPIO3_A3)
unnamed: R59.3, U1.102 (SDMMC_D2/JTAG_TCK_M0/GPIO3_A4)
unnamed: R59.4, U1.101 (SDMMC_D3/JTAG_TMS_M0/GPIO3_A5)
unnamed: R81.1, U1.40 (VO_LCDC_D13/DSMC_CSN0/FLEXBUS1_D14/FLEX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)
VCC_3V3: C34.2, Q5.2 (S), R55.2, R66.2; also elsewhere on the board

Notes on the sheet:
Close to Connector
SDMMC0_PWREN=L VCC3V3_SD=3.3V(Default) SDMMC0_PWREN=H VCC3V3_SD=0V

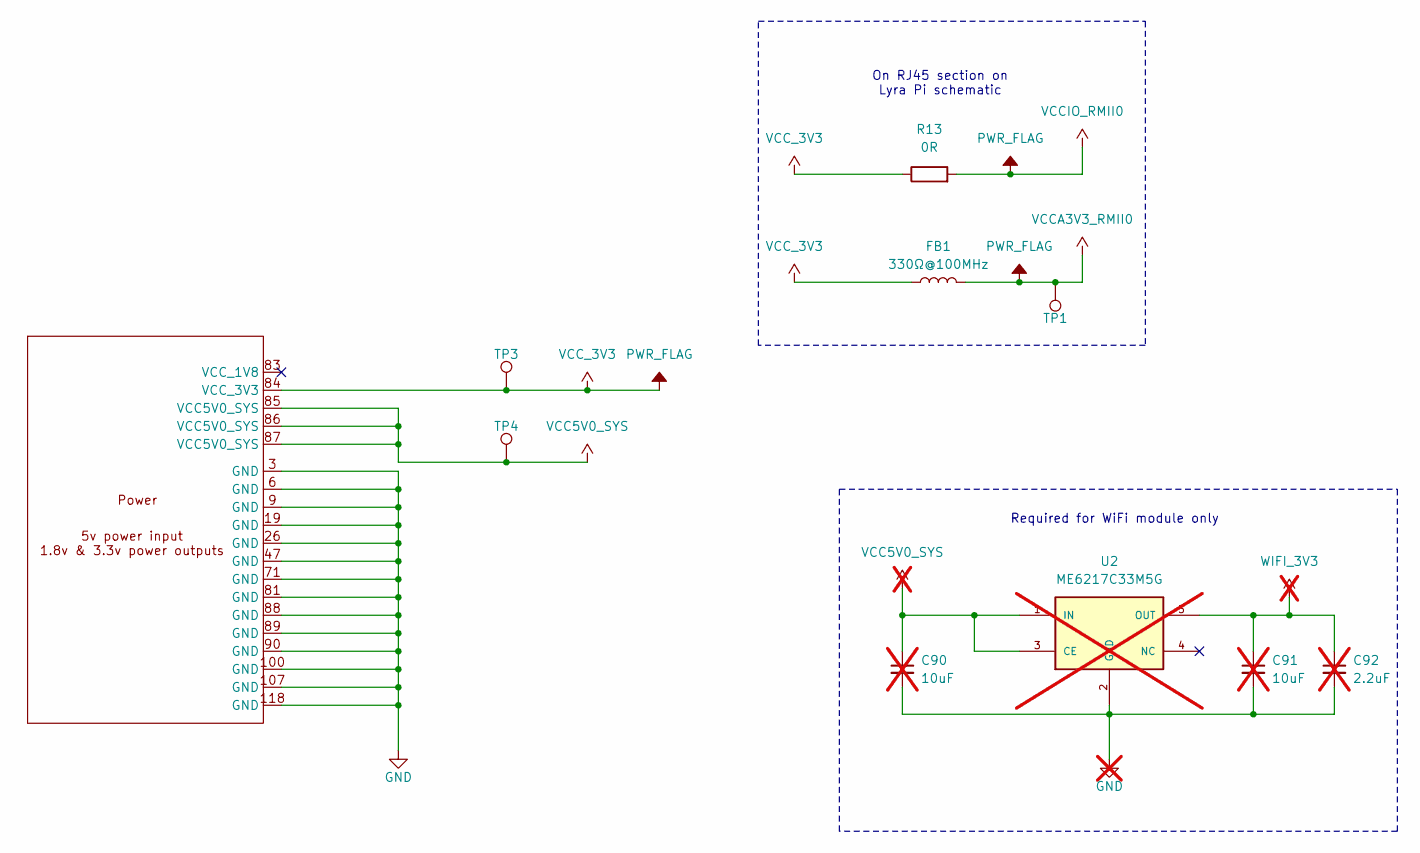
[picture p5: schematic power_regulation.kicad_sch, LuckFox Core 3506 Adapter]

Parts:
C90, C91: 10uF; C_0603_1608Metric; LCSC C19702; not fitted
C92: 2.2uF; C_0603_1608Metric; LCSC C23630; not fitted
FB1: 330Ω@100MHz; L_0603_1608Metric; LCSC C88989
R13: 0R; R_0603_1608Metric; LCSC C21189
TP1: 3.3v RMIIO; TestPoint-1.0mm
TP3: 3.3v; TestPoint-1.0mm
TP4: 5v; TestPoint-1.0mm
U1: CORE3506_[32_32]_120P
U2: ME6217C33M5G; SOT23-5; M_PART_NUMBER ME6217C33M5G; LCSC C427602; not fitted

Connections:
GND: C90.2, C91.2, C92.2, U1.3 (GND), U1.6 (GND), U1.9 (GND), U1.19 (GND), U1.26 (GND), U1.47 (GND), U1.71 (GND), U1.81 (GND), U1.88 (GND), U1.89 (GND), U1.90 (GND), U1.100 (GND), U1.107 (GND), U1.118 (GND), U2.2 (GND); also elsewhere on the board
VCC5V0_SYS: C90.1, TP4.1 (1_1), U1.85 (VCC5V0_SYS), U1.86 (VCC5V0_SYS), U1.87 (VCC5V0_SYS), U2.1 (IN), U2.3 (CE); also elsewhere on the board
VCCA3V3_RMII0: FB1.2, TP1.1 (1_1); also elsewhere on the board
VCCIO_RMII0: R13.2; also elsewhere on the board
VCC_3V3: FB1.1, R13.1, TP3.1 (1_1), U1.84 (VCC_3V3); also elsewhere on the board
WIFI_3V3: C91.1, C92.1, U2.5 (OUT)

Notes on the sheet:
On RJ45 section on Lyra Pi schematic
Required for WiFi module only

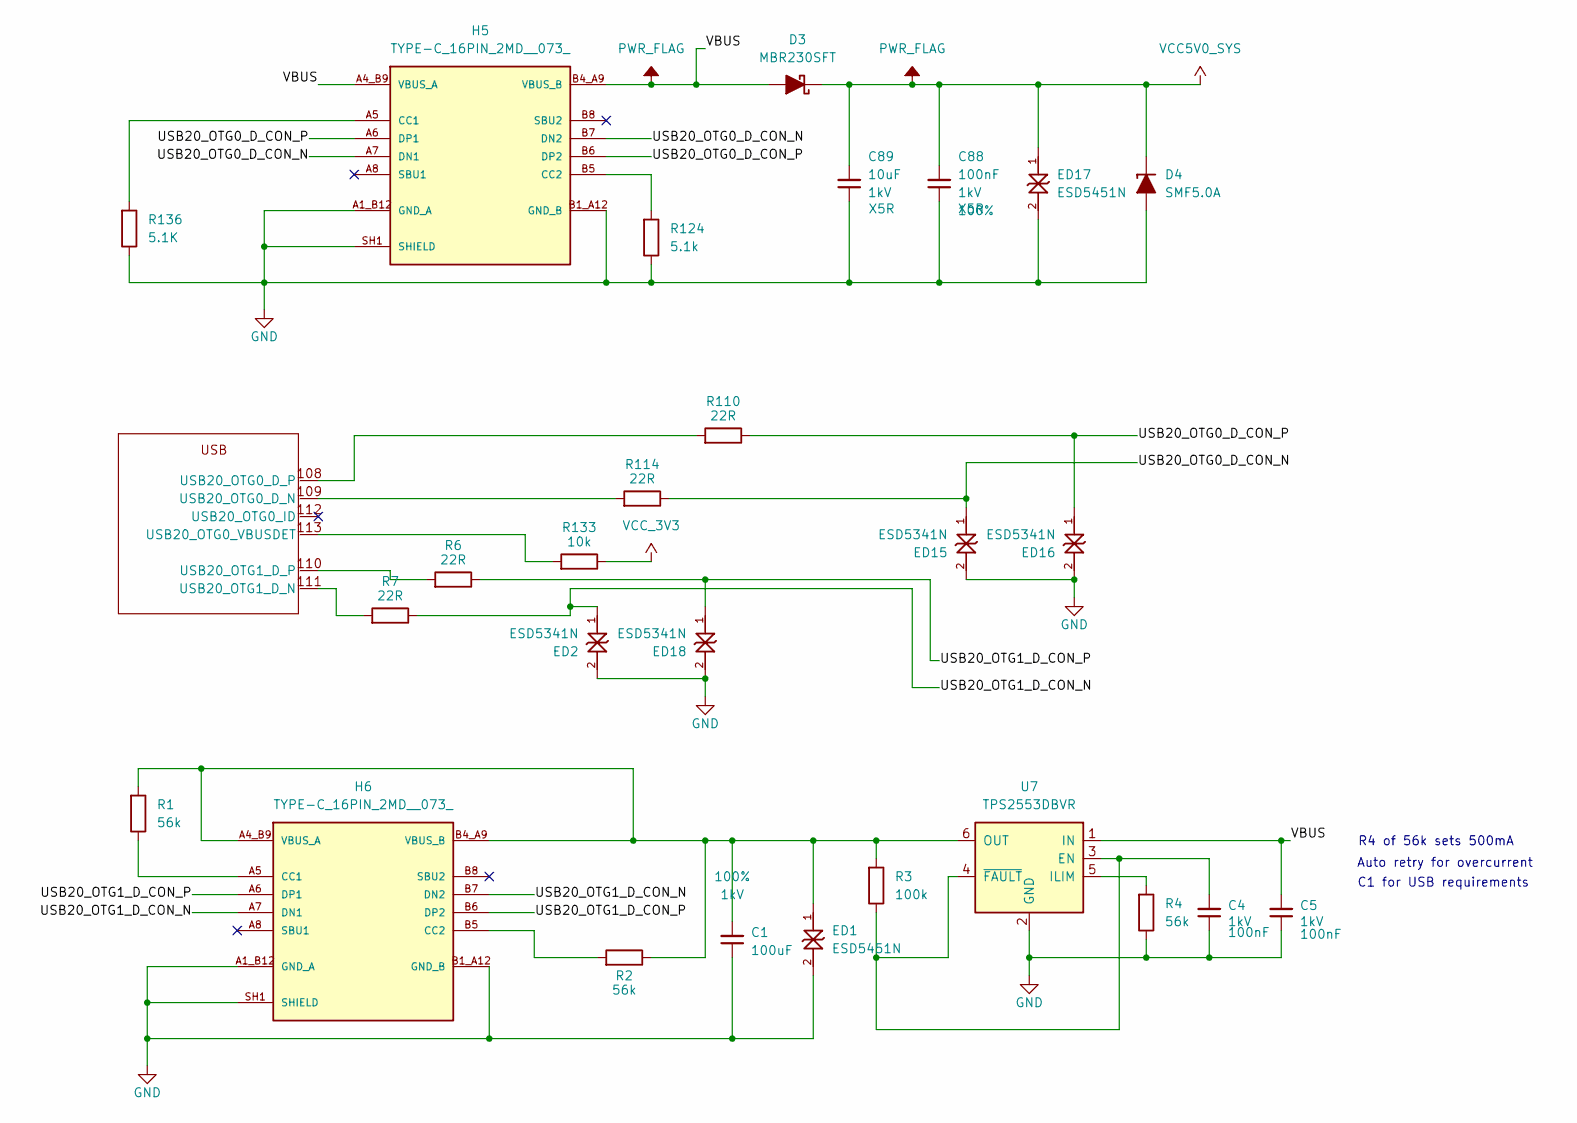
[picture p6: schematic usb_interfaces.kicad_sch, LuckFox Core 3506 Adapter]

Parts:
C1: 100uF; C_1206_3216Metric; Voltage 1kV; Tolerance 100%; LCSC C15008
C4, C5, C88: 100nF; C_0603_1608Metric; Voltage 1kV; Tolerance 100%; LCSC C14663
C89: 10uF; C_0603_1608Metric; Voltage 1kV; Tolerance 100%; LCSC C19702
D3: MBR230SFT; D_SOD-123F; LCSC C5377812
D4: SMF5.0A; D_SOD-123F; LCSC C19077498
ED1, ED17: ESD5451N; D_0402_1005Metric; LCSC C2936977
ED2, ED15, ED16, ED18: ESD5341N; D_0402_1005Metric; LCSC C20612964
H5, H6: TYPE-C_16PIN_2MD__073_; TYPE-C_16PIN_2MD_073; LCSC C2765186
R1, R2, R4: 56k; R_0603_1608Metric; LCSC C23206
R3: 100k; R_0603_1608Metric; LCSC C25803
R6, R7, R110, R114: 22R; R_0603_1608Metric; LCSC C23345
R124: 5.1k; R_0603_1608Metric; LCSC C23186
R133: 10k; R_0603_1608Metric; LCSC C25804
R136: 5.1K; R_0603_1608Metric; LCSC C23186
U1: CORE3506_[32_32]_120P
U7: TPS2553DBVR; SOT-23-6; LCSC C55266

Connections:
/USB interfaces/USB20_OTG0_D_CON_N: ED15.1 (A1), H5.A7 (DN1), H5.B7 (DN2), R114.2
/USB interfaces/USB20_OTG0_D_CON_P: ED16.1 (A1), H5.A6 (DP1), H5.B6 (DP2), R110.2
/USB interfaces/USB20_OTG1_D_CON_N: ED2.1 (A1), H6.A7 (DN1), H6.B7 (DN2), R7.2
/USB interfaces/USB20_OTG1_D_CON_P: ED18.1 (A1), H6.A6 (DP1), H6.B6 (DP2), R6.2
/USB interfaces/VBUS: C5.2, D3.2 (A), H5.A4_B9 (VBUS_A), H5.B4_A9 (VBUS_B), U7.1 (IN)
GND: C1.1, C4.1, C5.1, C88.1, C89.1, D4.2 (A), ED1.2 (A2), ED2.2 (A2), ED15.2 (A2), ED16.2 (A2), ED17.2 (A2), ED18.2 (A2), H5.A1_B12 (GND_A), H5.B1_A12 (GND_B), H5.SH1 (SHIELD), H5.SH2 (SHIELD), H5.SH3 (SHIELD), H5.SH4 (SHIELD), H6.A1_B12 (GND_A), H6.B1_A12 (GND_B), H6.SH1 (SHIELD), H6.SH2 (SHIELD), H6.SH3 (SHIELD), H6.SH4 (SHIELD), R4.2, R124.2, R136.2, U7.2 (GND); also elsewhere on the board
unnamed: C1.2, ED1.1 (A1), H6.A4_B9 (VBUS_A), H6.B4_A9 (VBUS_B), R1.1, R2.2, R3.1, U7.6 (OUT)
unnamed: H5.A5 (CC1), R136.1
unnamed: H5.B5 (CC2), R124.1
unnamed: H6.A5 (CC1), R1.2
unnamed: H6.B5 (CC2), R2.1
unnamed: R114.1, U1.109 (USB20_OTG0_D_N)
unnamed: R110.1, U1.108 (USB20_OTG0_D_P)
unnamed: R133.1, U1.113 (USB20_OTG0_VBUSDET)
unnamed: R7.1, U1.111 (USB20_OTG1_D_N)
unnamed: R6.1, U1.110 (USB20_OTG1_D_P)
unnamed: C4.2, R3.2, U7.3 (EN), U7.4 (~FAULT)
unnamed: R4.1, U7.5 (ILIM)
VCC5V0_SYS: C88.2, C89.2, D3.1 (K), D4.1 (K), ED17.1 (A1); also elsewhere on the board
VCC_3V3: R133.2; also elsewhere on the board

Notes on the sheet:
R4 of 56k sets 500mA
C1 for USB requirements
Auto retry for overcurrent

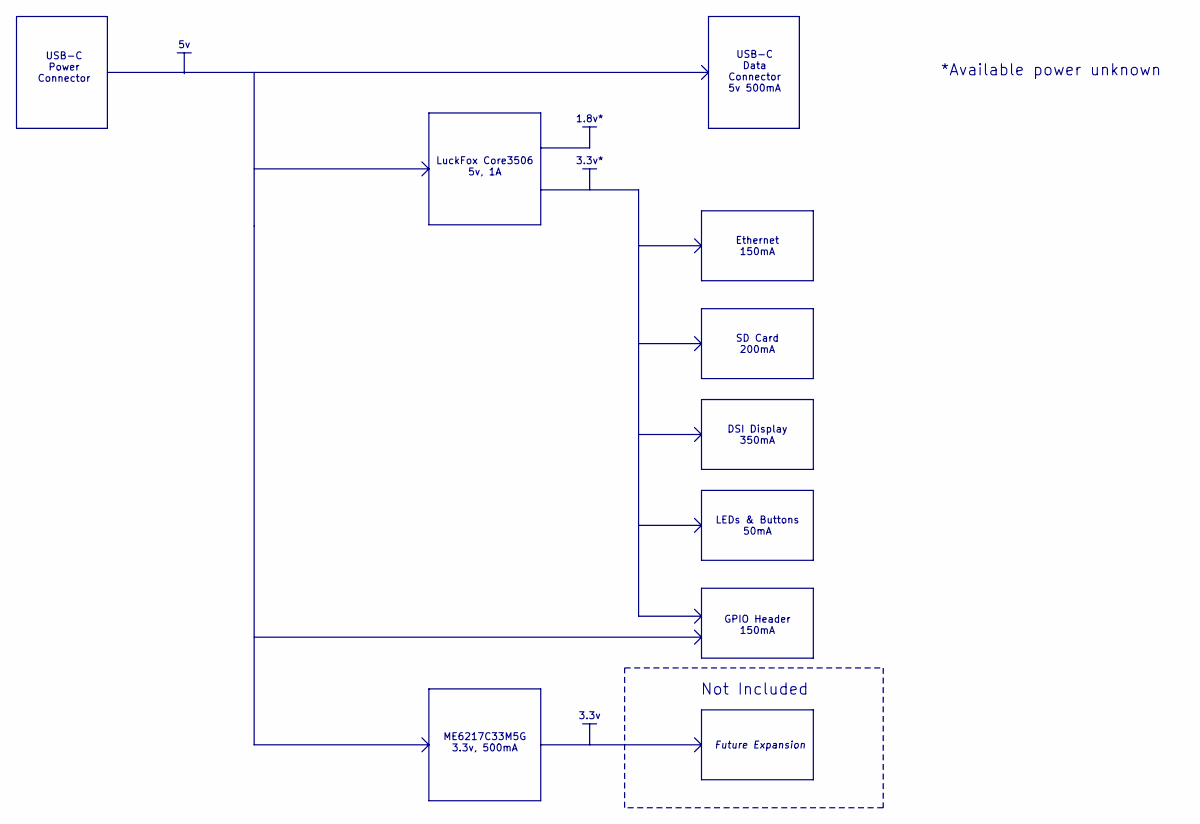
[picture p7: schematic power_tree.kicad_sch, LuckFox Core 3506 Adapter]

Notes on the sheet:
GPIO Header 150mA
Ethernet 150mA
*Available power unknown
DSI Display 350mA
LEDs & Buttons 50mA
USB-C Data Connector 5v 500mA
3.3v
USB-C Power Connector
1.8v*
LuckFox Core3506 5v, 1A
ME6217C33M5G 3.3v, 500mA
3.3v*
SD Card 200mA
Not Included
Future Expansion

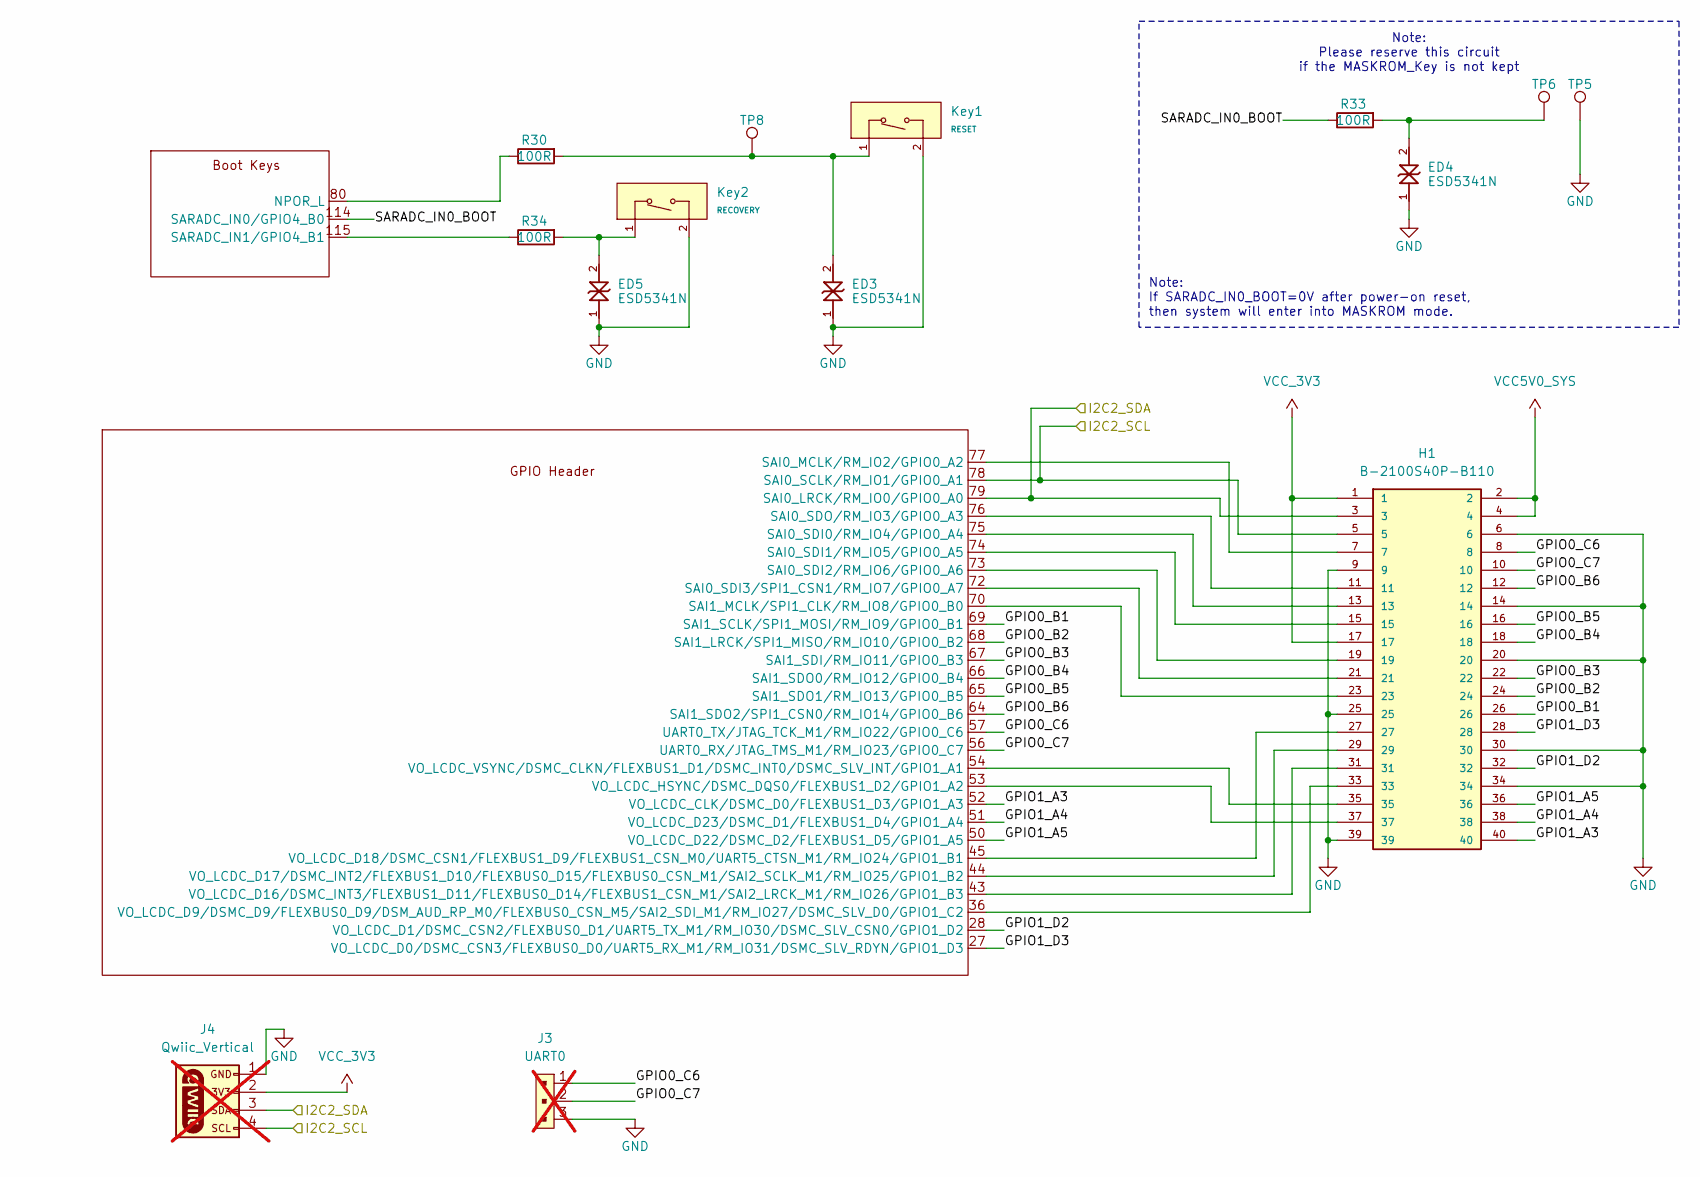
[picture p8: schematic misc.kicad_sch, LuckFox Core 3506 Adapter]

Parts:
ED3, ED4, ED5: ESD5341N; D_0402_1005Metric; LCSC C20612964
H1: B-2100S40P-B110; PinHeader_2x20_P2.54mm_Vertical; LCSC C124383
J3: UART0; PinHeader_1x3_P2.54_Drill1.1mm; MPN 640456-3; Digi-Key_PN A19470-ND; not fitted
J4: Qwiic_Vertical; JST_1x04_P1.0mm_Vertical_SMD; not fitted
Key1: RESET; SW_TS-1088-AR02016; Voltage Rating (Dc) 12V; Part TS-1088-AR02016; LCSC C720477
Key2: RECOVERY; SW_TS-1088-AR02016; Voltage Rating (Dc) 12V; Part TS-1088-AR02016; LCSC C720477
R30, R33, R34: 100R; R_0603_1608Metric; LCSC C22775
TP5: GND; TestPoint-1.0mm
TP6: BOOT; TestPoint-1.0mm
TP8: NPOR_L; TestPoint-1.0mm
U1: CORE3506_[32_32]_120P

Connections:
/DSI/I2C2_SCL: H1.5, J4.4, U1.78 (SAI0_SCLK/RM_IO1/GPIO0_A1); also elsewhere on the board
/DSI/I2C2_SDA: H1.3, J4.3, U1.79 (SAI0_LRCK/RM_IO0/GPIO0_A0); also elsewhere on the board
/GPIO Header & boot keys/GPIO0_B1: H1.26, U1.69 (SAI1_SCLK/SPI1_MOSI/RM_IO9/GPIO0_B1)
/GPIO Header & boot keys/GPIO0_B2: H1.24, U1.68 (SAI1_LRCK/SPI1_MISO/RM_IO10/GPIO0_B2)
/GPIO Header & boot keys/GPIO0_B3: H1.22, U1.67 (SAI1_SDI/RM_IO11/GPIO0_B3)
/GPIO Header & boot keys/GPIO0_B4: H1.18, U1.66 (SAI1_SDO0/RM_IO12/GPIO0_B4)
/GPIO Header & boot keys/GPIO0_B5: H1.16, U1.65 (SAI1_SDO1/RM_IO13/GPIO0_B5)
/GPIO Header & boot keys/GPIO0_B6: H1.12, U1.64 (SAI1_SDO2/SPI1_CSN0/RM_IO14/GPIO0_B6)
/GPIO Header & boot keys/GPIO0_C6: H1.8, J3.1, U1.57 (UART0_TX/JTAG_TCK_M1/RM_IO22/GPIO0_C6)
/GPIO Header & boot keys/GPIO0_C7: H1.10, J3.2, U1.56 (UART0_RX/JTAG_TMS_M1/RM_IO23/GPIO0_C7)
/GPIO Header & boot keys/GPIO1_A3: H1.40, U1.52 (VO_LCDC_CLK/DSMC_D0/FLEXBUS1_D3/GPIO1_A3)
/GPIO Header & boot keys/GPIO1_A4: H1.38, U1.51 (VO_LCDC_D23/DSMC_D1/FLEXBUS1_D4/GPIO1_A4)
/GPIO Header & boot keys/GPIO1_A5: H1.36, U1.50 (VO_LCDC_D22/DSMC_D2/FLEXBUS1_D5/GPIO1_A5)
/GPIO Header & boot keys/GPIO1_D2: H1.32, U1.28 (VO_LCDC_D1/DSMC_CSN2/FLEXBUS0_D1/UART5_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)
/GPIO Header & boot keys/GPIO1_D3: H1.28, U1.27 (VO_LCDC_D0/DSMC_CSN3/FLEXBUS0_D0/UART5_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)
/GPIO Header & boot keys/SARADC_IN0_BOOT: R33.2, U1.114 (SARADC_IN0/GPIO4_B0)
GND: ED3.1 (A1), ED4.1 (A1), ED5.1 (A1), H1.6, H1.9, H1.14, H1.20, H1.25, H1.30, H1.34, H1.39, J3.3, J4.1, Key1.2 (B), Key2.2 (B), TP5.1 (1_1); also elsewhere on the board
unnamed: ED3.2 (A2), Key1.1 (A), R30.1, TP8.1 (1_1)
unnamed: ED4.2 (A2), R33.1, TP6.1 (1_1)
unnamed: ED5.2 (A2), Key2.1 (A), R34.1
unnamed: R30.2, U1.80 (NPOR_L)
unnamed: R34.2, U1.115 (SARADC_IN1/GPIO4_B1)
unnamed: H1.7, U1.77 (SAI0_MCLK/RM_IO2/GPIO0_A2)
unnamed: H1.13, U1.75 (SAI0_SDI0/RM_IO4/GPIO0_A4)
unnamed: H1.15, U1.74 (SAI0_SDI1/RM_IO5/GPIO0_A5)
unnamed: H1.19, U1.73 (SAI0_SDI2/RM_IO6/GPIO0_A6)
unnamed: H1.21, U1.72 (SAI0_SDI3/SPI1_CSN1/RM_IO7/GPIO0_A7)
unnamed: H1.11, U1.76 (SAI0_SDO/RM_IO3/GPIO0_A3)
unnamed: H1.23, U1.70 (SAI1_MCLK/SPI1_CLK/RM_IO8/GPIO0_B0)
unnamed: H1.33, U1.36 (VO_LCDC_D9/DSMC_D9/FLEXBUS0_D9/DSM_AUD_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)
unnamed: H1.31, U1.43 (VO_LCDC_D16/DSMC_INT3/FLEXBUS1_D11/FLEX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)
unnamed: H1.29, U1.44 (VO_LCDC_D17/DSMC_INT2/FLEXBUS1_D10/FLEX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)
unnamed: H1.27, U1.45 (VO_LCDC_D18/DSMC_CSN1/FLEXBUS1_D9/FLEXB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)
unnamed: H1.37, U1.53 (VO_LCDC_HSYNC/DSMC_DQS0/FLEXBUS1_D2/GPI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)
unnamed: H1.35, U1.54 (VO_LCDC_VSYNC/DSMC_CLKN/FLEXBUS1_D1/DSM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)
VCC5V0_SYS: H1.2, H1.4; also elsewhere on the board
VCC_3V3: H1.1, H1.17, J4.2; also elsewhere on the board

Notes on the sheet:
Note: Please reserve this circuit if the MASKROM_Key is not kept
Note: If SARADC_IN0_BOOT=0V after power-on reset, then system will enter into MASKROM mode.

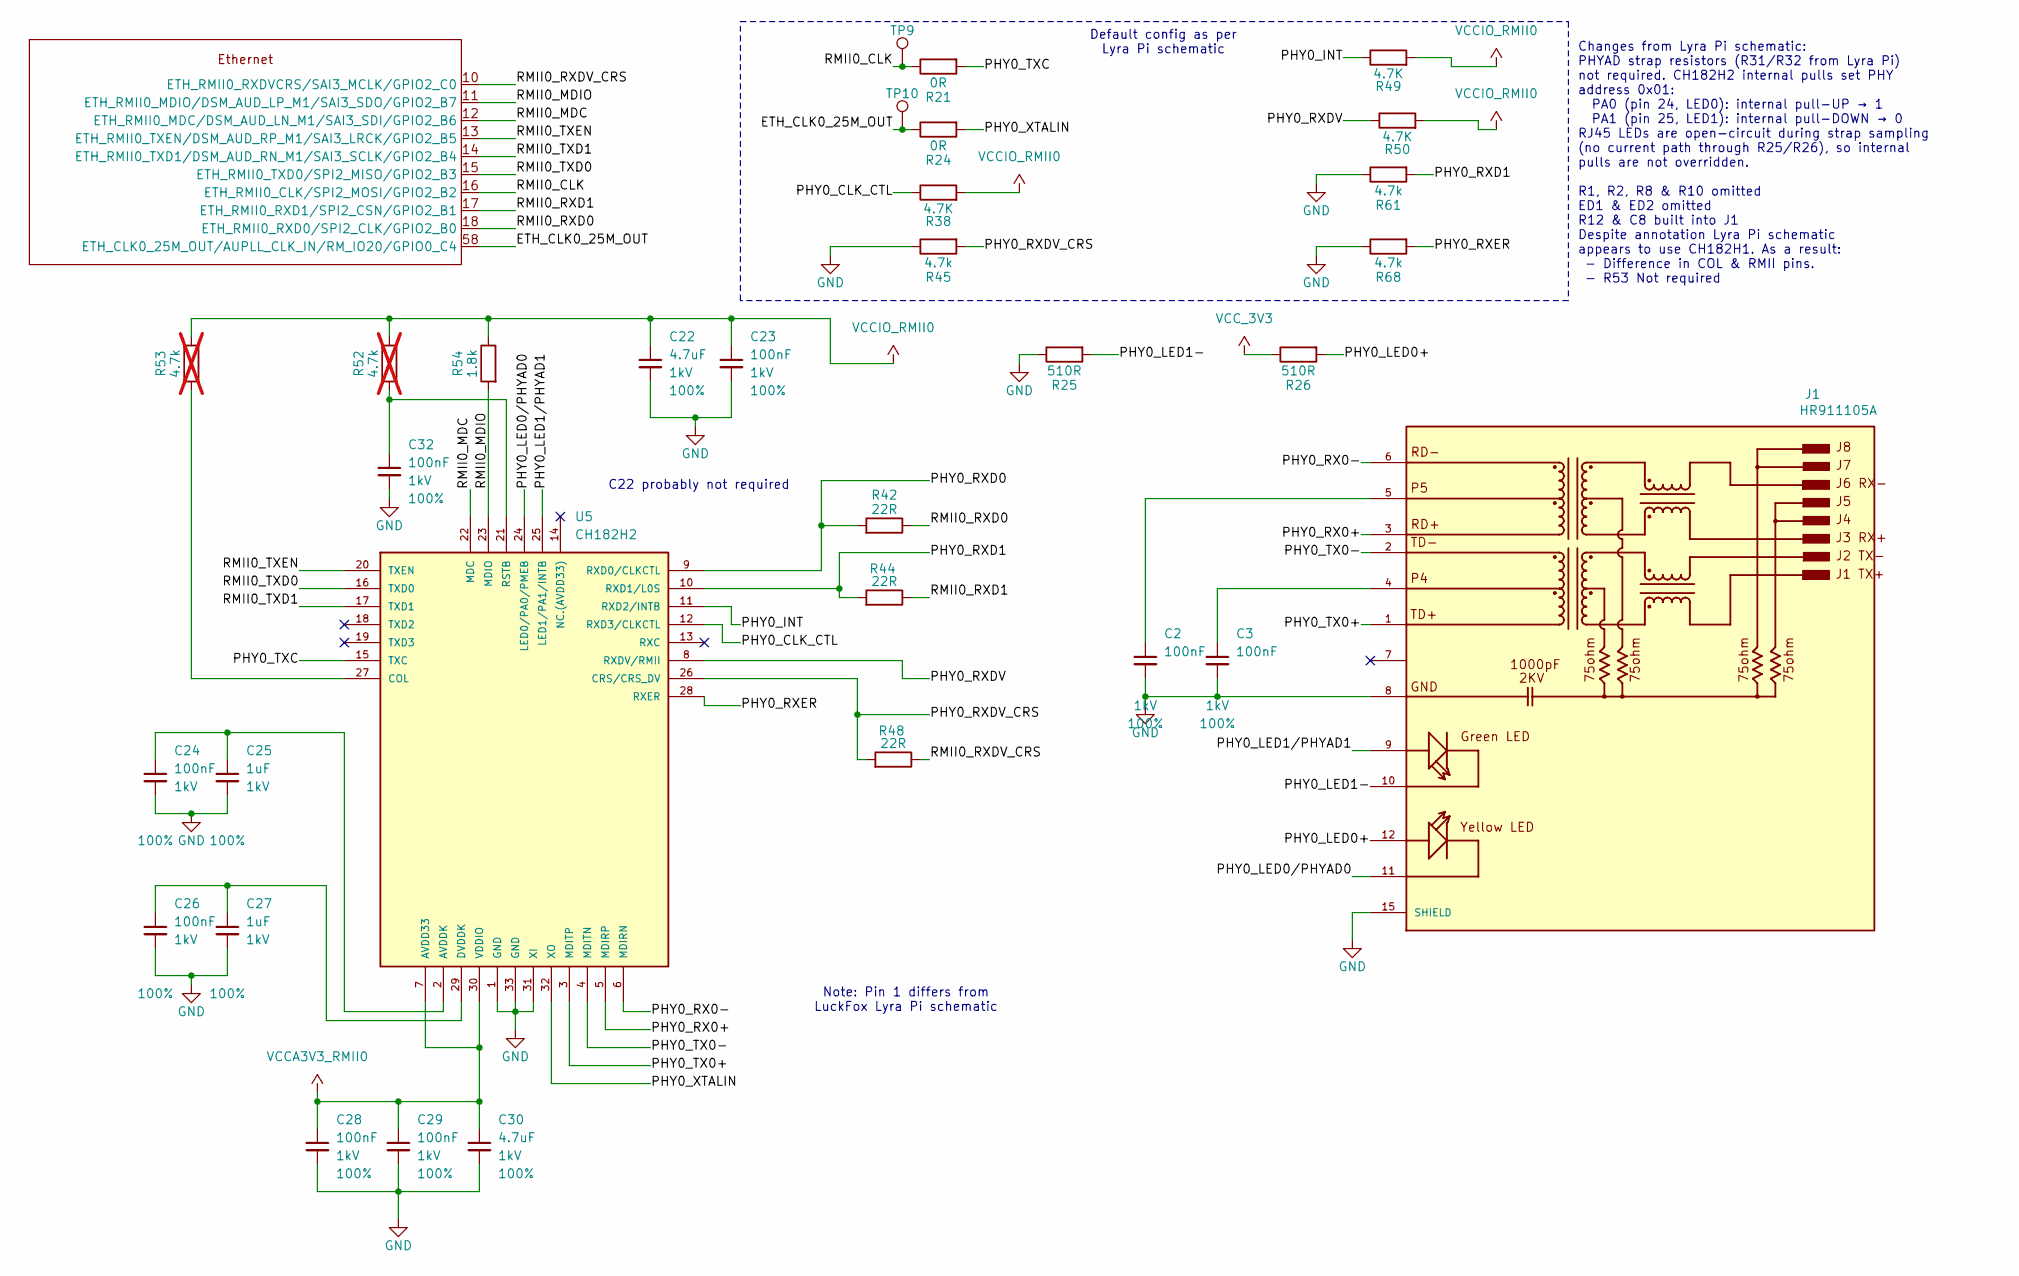
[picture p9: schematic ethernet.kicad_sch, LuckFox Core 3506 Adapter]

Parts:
C2, C3, C23, C24, C26, C28, C29, C32: 100nF; C_0603_1608Metric; Voltage 1kV; Tolerance 100%; LCSC C14663
C22, C30: 4.7uF; C_0603_1608Metric; Voltage 1kV; Tolerance 100%; LCSC C19666
C25, C27: 1uF; C_0603_1608Metric; Voltage 1kV; Tolerance 100%; LCSC C15849
J1: HR911105A; HANRUN_HR911105A; LCSC C12074
R21, R24: 0R; R_0603_1608Metric; LCSC C21189
R25, R26: 510R; R_0603_1608Metric; LCSC C23193
R38, R49, R50: 4.7K; R_0603_1608Metric; LCSC C23162
R42, R44, R48: 22R; R_0603_1608Metric; LCSC C23345
R45, R61, R68: 4.7k; R_0603_1608Metric; LCSC C23162
R52, R53: 4.7k; R_0603_1608Metric; LCSC C23162; not fitted
R54: 1.8k; R_0603_1608Metric; LCSC C4177
TP9: RMII0_CLK; TestPoint-1.0mm
TP10: ETH_CLK; TestPoint-1.0mm
U1: CORE3506_[32_32]_120P
U5: CH182H2; QFN-32-1EP_5x5mm_P0.5mm_EP3.45x3.45mm; LCSC C41427683

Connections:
/Ethernet/ETH_CLK0_25M_OUT: R24.2, TP10.1 (1_1), U1.58 (ETH_CLK0_25M_OUT/AUPLL_CLK_IN/RM_IO20/G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)
/Ethernet/PHY0_CLK_CTL: R38.1, U5.12 (RXD3/CLKCTL)
/Ethernet/PHY0_INT: R49.1, U5.11 (RXD2/INTB)
/Ethernet/PHY0_LED0+: J1.12, R26.1
/Ethernet/PHY0_LED0/PHYAD0: J1.11, U5.24 (LED0/PA0/PMEB)
/Ethernet/PHY0_LED1-: J1.10, R25.1
/Ethernet/PHY0_LED1/PHYAD1: J1.9, U5.25 (LED1/PA1/INTB)
/Ethernet/PHY0_RX0+: J1.3, U5.5 (MDIRP)
/Ethernet/PHY0_RX0-: J1.6, U5.6 (MDIRN)
/Ethernet/PHY0_RXD0: R42.1, U5.9 (RXD0/CLKCTL)
/Ethernet/PHY0_RXD1: R44.1, R61.1, U5.10 (RXD1/L0S)
/Ethernet/PHY0_RXDV: R50.1, U5.8 (RXDV/RMII)
/Ethernet/PHY0_RXDV_CRS: R45.1, R48.1, U5.26 (CRS/CRS_DV)
/Ethernet/PHY0_RXER: R68.1, U5.28 (RXER)
/Ethernet/PHY0_TX0+: J1.1, U5.3 (MDITP)
/Ethernet/PHY0_TX0-: J1.2, U5.4 (MDITN)
/Ethernet/PHY0_TXC: R21.1, U5.15 (TXC)
/Ethernet/PHY0_XTALIN: R24.1, U5.32 (XO)
/Ethernet/RMII0_CLK: R21.2, TP9.1 (1_1), U1.16 (ETH_RMII0_CLK/SPI2_MOSI/GPIO2_B2)
/Ethernet/RMII0_MDC: U1.12 (ETH_RMII0_MDC/DSM_AUD_LN_M1/SAI3_SDI/GP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), U5.22 (MDC)
/Ethernet/RMII0_MDIO: R54.1, U1.11 (ETH_RMII0_MDIO/DSM_AUD_LP_M1/SAI3_SDO/G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), U5.23 (MDIO)
/Ethernet/RMII0_RXD0: R42.2, U1.18 (ETH_RMII0_RXD0/SPI2_CLK/GPIO2_B0)
/Ethernet/RMII0_RXD1: R44.2, U1.17 (ETH_RMII0_RXD1/SPI2_CSN/GPIO2_B1)
/Ethernet/RMII0_RXDV_CRS: R48.2, U1.10 (ETH_RMII0_RXDVCRS/SAI3_MCLK/GPIO2_C0)
/Ethernet/RMII0_TXD0: U1.15 (ETH_RMII0_TXD0/SPI2_MISO/GPIO2_B3), U5.16 (TXD0)
/Ethernet/RMII0_TXD1: U1.14 (ETH_RMII0_TXD1/DSM_AUD_RN_M1/SAI3_SCLK/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), U5.17 (TXD1)
/Ethernet/RMII0_TXEN: U1.13 (ETH_RMII0_TXEN/DSM_AUD_RP_M1/SAI3_LRCK/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), U5.20 (TXEN)
GND: C2.2, C3.2, C22.2, C23.2, C24.2, C25.2, C26.2, C27.2, C28.2, C29.2, C30.2, C32.2, J1.8, J1.15 (SHIELD), J1.16 (SHIELD), R25.2, R45.2, R61.2, R68.2, U5.1 (GND), U5.31 (XI), U5.33 (GND); also elsewhere on the board
unnamed: C2.1, J1.5
unnamed: C3.1, J1.4
unnamed: C24.1, C25.1, U5.2 (AVDDK)
unnamed: R53.1, U5.27 (COL)
unnamed: C26.1, C27.1, U5.29 (DVDDK)
unnamed: C32.1, R52.1, U5.21 (RSTB)
VCCA3V3_RMII0: C28.1, C29.1, C30.1, U5.7 (AVDD33), U5.30 (VDDIO); also elsewhere on the board
VCCIO_RMII0: C22.1, C23.1, R38.2, R49.2, R50.2, R52.2, R53.2, R54.2; also elsewhere on the board
VCC_3V3: R26.2; also elsewhere on the board

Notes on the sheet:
Default config as per Lyra Pi schematic
Note: Pin 1 differs from LuckFox Lyra Pi schematic
C22 probably not required
Changes from Lyra Pi schematic: PHYAD strap resistors (R31/R32 from Lyra Pi) not required. CH182H2 internal pulls set PHY address 0x01: PA0 (pin 24, LED0): internal pull-UP → 1 PA1 (pin 25, LED1): internal pull-DOWN → 0 RJ45 LEDs are open-circuit during strap sampling (no current path through R25/R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

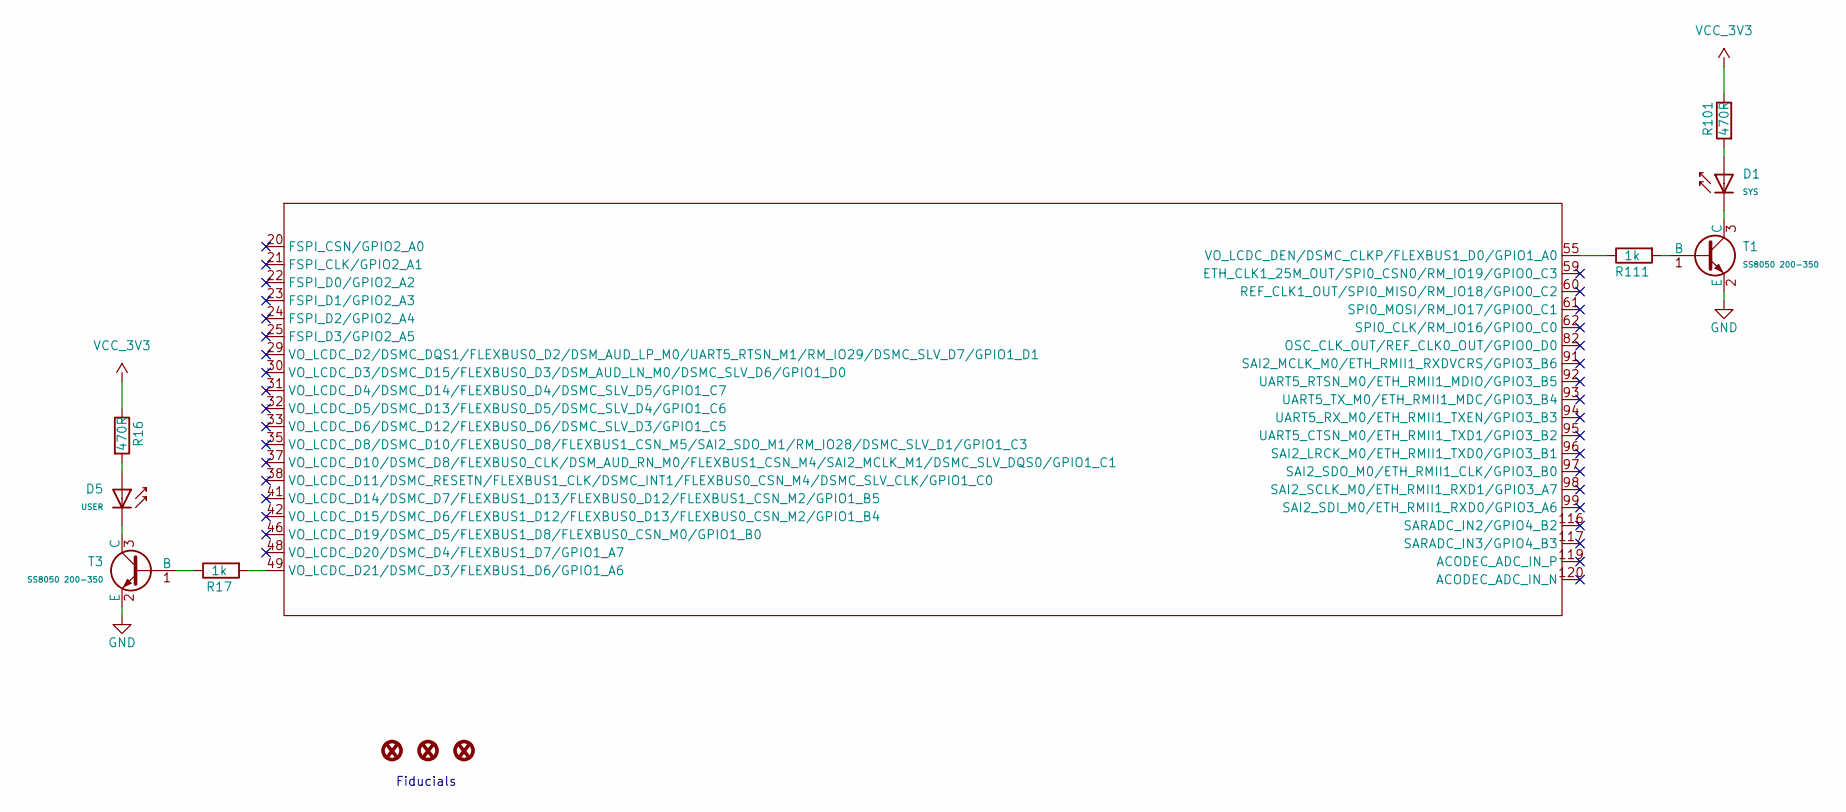
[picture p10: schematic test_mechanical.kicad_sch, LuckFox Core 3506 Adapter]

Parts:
D1: SYS; D_0805; Part KT-0805G; LCSC C2297
D5: USER; D_0805; Part KT-0805G; LCSC C2297
FID1, FID2, FID3: Fiducial_0.5mm; Fiducial_1mm_Mask2mm
R16, R101: 470R; R_0603_1608Metric; LCSC C23179
R17, R111: 1k; R_0603_1608Metric; LCSC C21190
T1, T3: SS8050 200-350; Q_SOT-23; Part SS8050(RANGE:200-350); LCSC C2150
U1: CORE3506_[32_32]_120P

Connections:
GND: T1.2 (E), T3.2 (E); also elsewhere on the board
unnamed: D1.2, R101.1
unnamed: D5.2, R16.1
unnamed: R111.1, T1.1 (B)
unnamed: D1.1, T1.3 (C)
unnamed: R17.2, T3.1 (B)
unnamed: D5.1, T3.3 (C)
unnamed: R17.1, U1.49 (VO_LCDC_D21/DSMC_D3/FLEXBUS1_D6/GPIO1_A6)
unnamed: R111.2, U1.55 (VO_LCDC_DEN/DSMC_CLKP/FLEXBUS1_D0/GPIO1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)
VCC_3V3: R16.2, R101.2; also elsewhere on the board

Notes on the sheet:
Fiducials

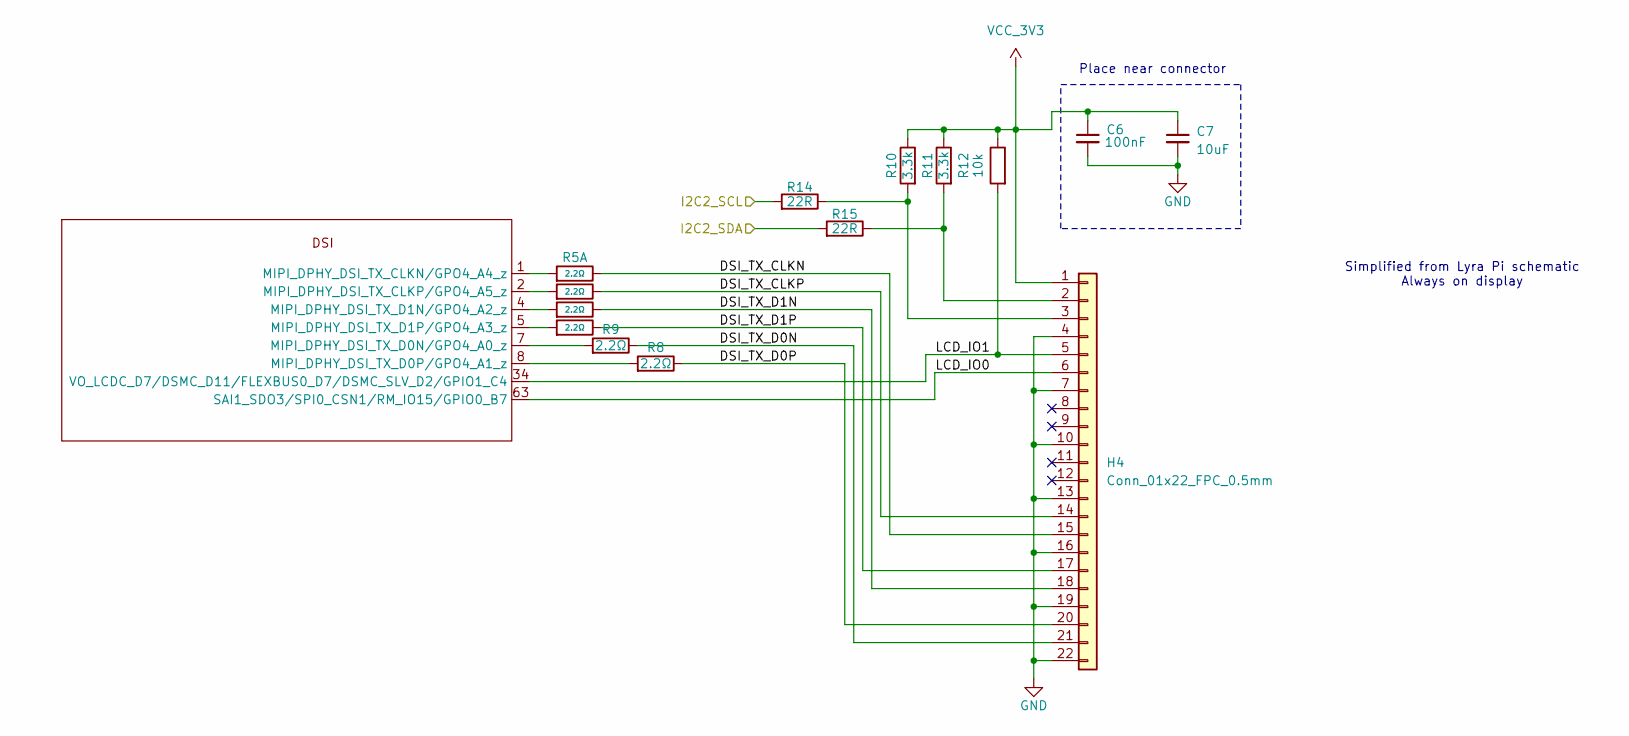
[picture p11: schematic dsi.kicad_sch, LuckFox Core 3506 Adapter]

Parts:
C6: 100nF; C_0603_1608Metric; Voltage 1kV; Tolerance 100%; LCSC C14663
C7: 10uF; C_0603_1608Metric; LCSC C19702
H4: Conn_01x22_FPC_0.5mm; FPC_1x22_P0.5mm_Horizontal_BottomContact; LCSC C262668
R5: 2.2Ω; R_0603x4; Tolerance ±5%; Part 4D03WGJ022JT5E; LCSC C12002
R8, R9: 2.2Ω; R_0603_1608Metric; LCSC C22939
R10, R11: 3.3k; R_0603_1608Metric; LCSC C22978
R12: 10k; R_0603_1608Metric; LCSC C25804
R14, R15: 22R; R_0603_1608Metric; LCSC C23345
U1: CORE3506_[32_32]_120P

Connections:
/DSI/DSI_TX_CLKN: H4.15, R5.5
/DSI/DSI_TX_CLKP: H4.14, R5.6
/DSI/DSI_TX_D0N: H4.21, R9.2
/DSI/DSI_TX_D0P: H4.20, R8.2
/DSI/DSI_TX_D1N: H4.18, R5.7
/DSI/DSI_TX_D1P: H4.17, R5.8
/DSI/I2C2_SCL: R14.1; also elsewhere on the board
/DSI/I2C2_SDA: R15.1; also elsewhere on the board
/DSI/LCD_IO0: H4.6, U1.63 (SAI1_SDO3/SPI0_CSN1/RM_IO15/GPIO0_B7)
/DSI/LCD_IO1: H4.5, R12.1, U1.34 (VO_LCDC_D7/DSMC_D11/FLEXBUS0_D7/DSMC_SL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)
GND: C6.2, C7.2, H4.4, H4.7, H4.10, H4.13, H4.16, H4.19, H4.22; also elsewhere on the board
unnamed: H4.2, R11.1, R15.2
unnamed: H4.3, R10.1, R14.2
unnamed: R5.4, U1.1 (MIPI_DPHY_DSI_TX_CLKN/GPO4_A4_z)
unnamed: R5.3, U1.2 (MIPI_DPHY_DSI_TX_CLKP/GPO4_A5_z)
unnamed: R9.1, U1.7 (MIPI_DPHY_DSI_TX_D0N/GPO4_A0_z)
unnamed: R8.1, U1.8 (MIPI_DPHY_DSI_TX_D0P/GPO4_A1_z)
unnamed: R5.2, U1.4 (MIPI_DPHY_DSI_TX_D1N/GPO4_A2_z)
unnamed: R5.1, U1.5 (MIPI_DPHY_DSI_TX_D1P/GPO4_A3_z)
VCC_3V3: C6.1, C7.1, H4.1, R10.2, R11.2, R12.2; also elsewhere on the board

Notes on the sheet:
Place near connector
Simplified from Lyra Pi schematic Always on display

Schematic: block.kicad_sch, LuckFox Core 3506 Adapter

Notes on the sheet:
RMII0 TX/RX MDIO/MDC
Booting: Recovery button released: 1. eMMC 2. SD Recovery button pressed at reset: Enumerate as USB device
NPOR_L SARADC_IN0 UART0_TX/RX
USB-C OTG1 (Host) 500mA Limit
Voltage Converter 5v to 3.3v LDO ME6217C33M5G
Power Flow: USB-C OTG0 VBUS → 5V Rail → SOM -> Ancillaries USB OTG1 powered from 5V rail via TPS2553 current limiter
USB-C Power & Flash
TF/SD Card SDMMC TF-110 Socket Card Detect
5v/ 1A
3.3v
VBUS Out
System Block Diagram
Boot & Debug MASKROM Button Reset Button UART Debug Header
Future Addition
GPIO Header 40 Pin
USB D+/D-
SDMMC CLK/CMD D0-D3
LuckFox Core3506 3 x Cortex A7 1 x Cortex M0 512MB DDR3L 8GB eMMC (Optional) 32mm x 32mm 120 castellated holes
Ethernet RMII0 HR911105A RJ45 + Magnetics
• USB-C OTG0: Device/Flash + Power Input • USB-C OTG1: Host (500mA protected) • RJ45 Ethernet (10/100 Mbps) • TF Card Socket (microSD) • UART Debug Header • Boot/Reset Buttons • Power & Status LEDs
VBUS Switch TPS2553 500mA Limit
USB D+/D- VBUSDET ID

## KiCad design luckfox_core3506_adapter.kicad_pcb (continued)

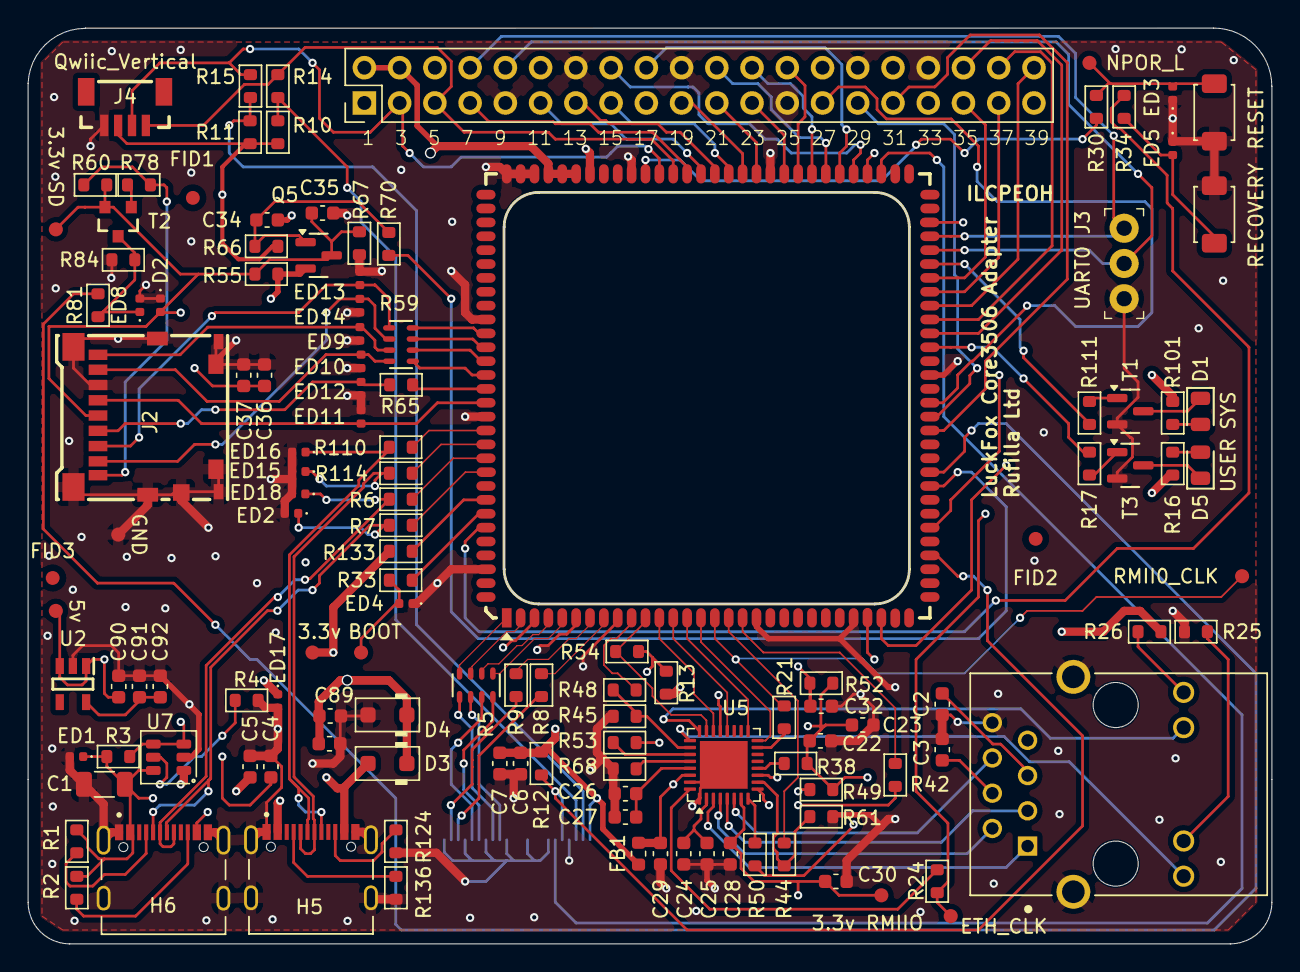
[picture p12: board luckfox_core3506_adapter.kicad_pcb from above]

Board: 4 copper layers, 89.7 x 66.0 mm, 131 parts (1 on the bottom side), 132 nets.

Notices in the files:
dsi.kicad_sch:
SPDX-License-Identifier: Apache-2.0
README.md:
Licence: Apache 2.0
